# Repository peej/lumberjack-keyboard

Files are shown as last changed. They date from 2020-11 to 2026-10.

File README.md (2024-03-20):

# Lumberjack - Through-hole ortholinear 60% keyboard PCB

Lumberjack is a split 5x12 ortholinear keyboard PCB using through-hole components only.

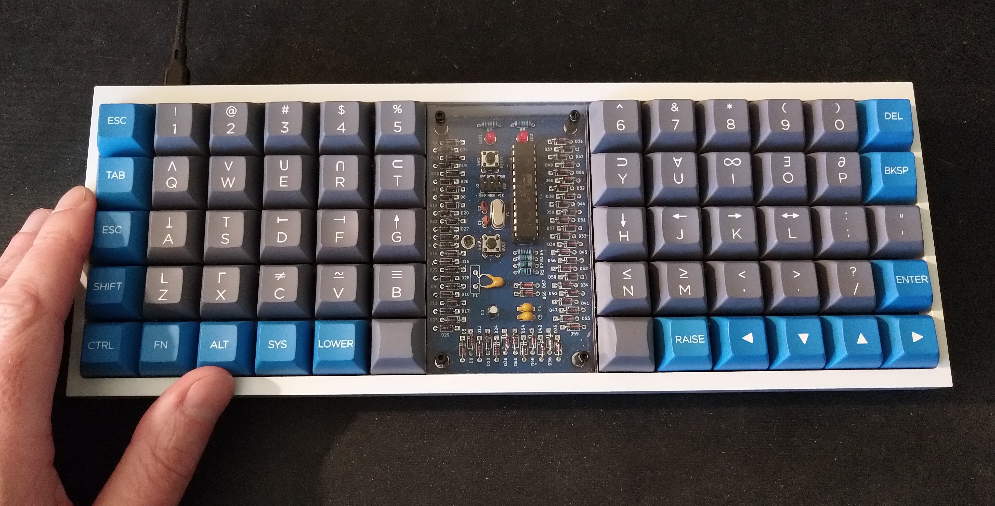
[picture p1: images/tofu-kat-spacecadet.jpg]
Tofu w/ KAT Space Cadet


The goal of this project is to build an all through-hole component ortholinear PCB that fits in a standard 60% tray mount case.

Inspired by the [Plaid keyboard](https://github.com/hsgw/plaid).

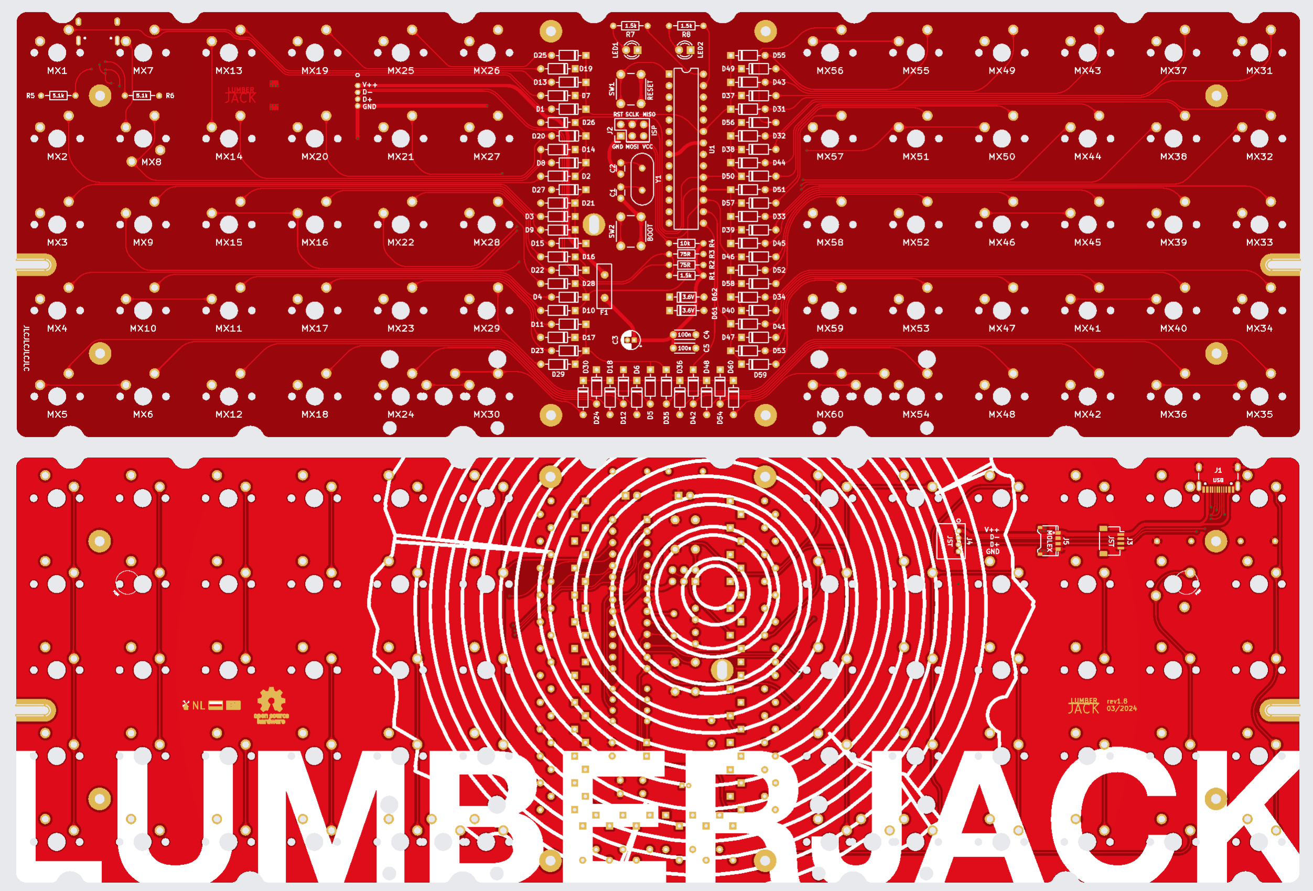
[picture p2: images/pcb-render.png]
PCB render


* Designed to be easy to build with minimal soldering experience.
* Get that visible component aesthetic in a standard 60% tray-mount case.
* 12 pin USB-C or JST connector.
* Plateless or with FR4 switch plates.

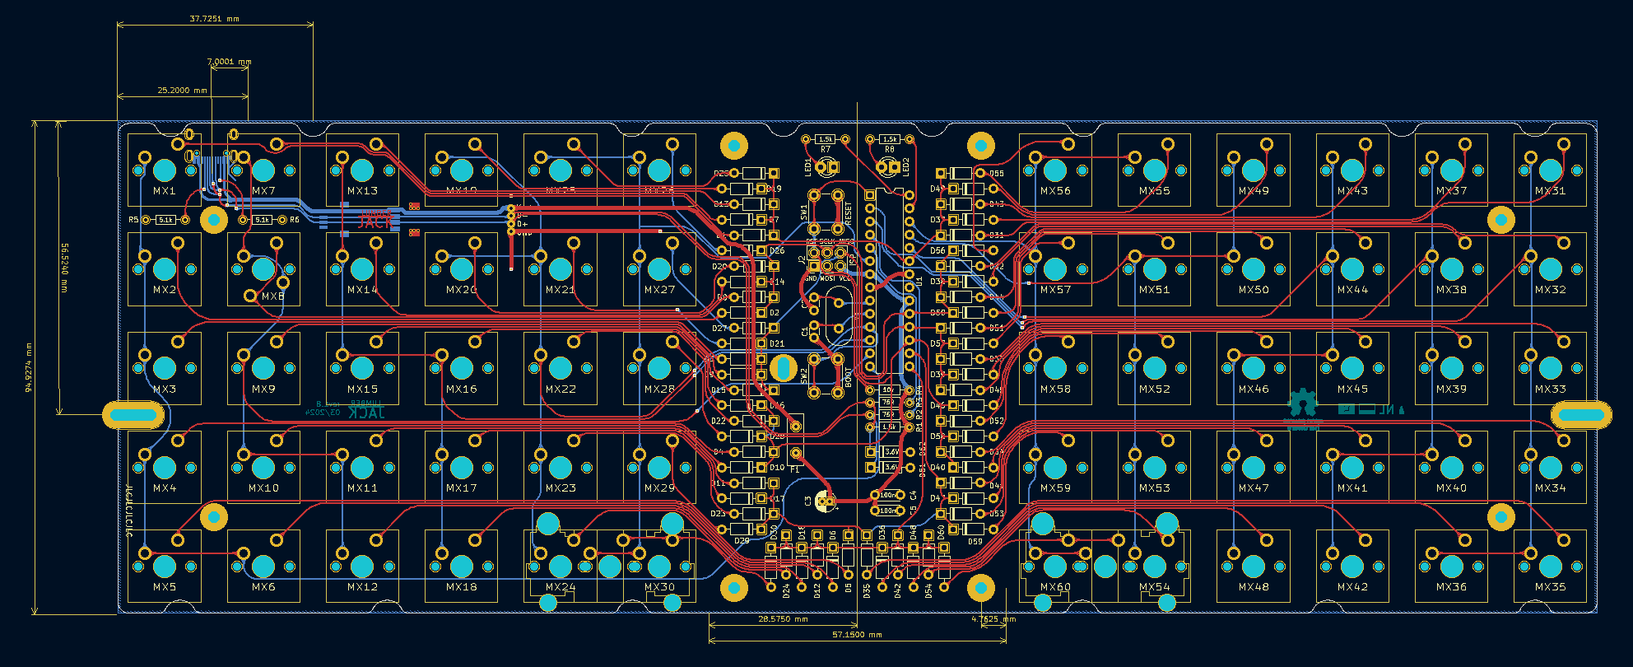
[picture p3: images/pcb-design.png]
PCB design


# Ordering parts

See the [Bill of materials](BOM.md) for a detailed list of the required parts.

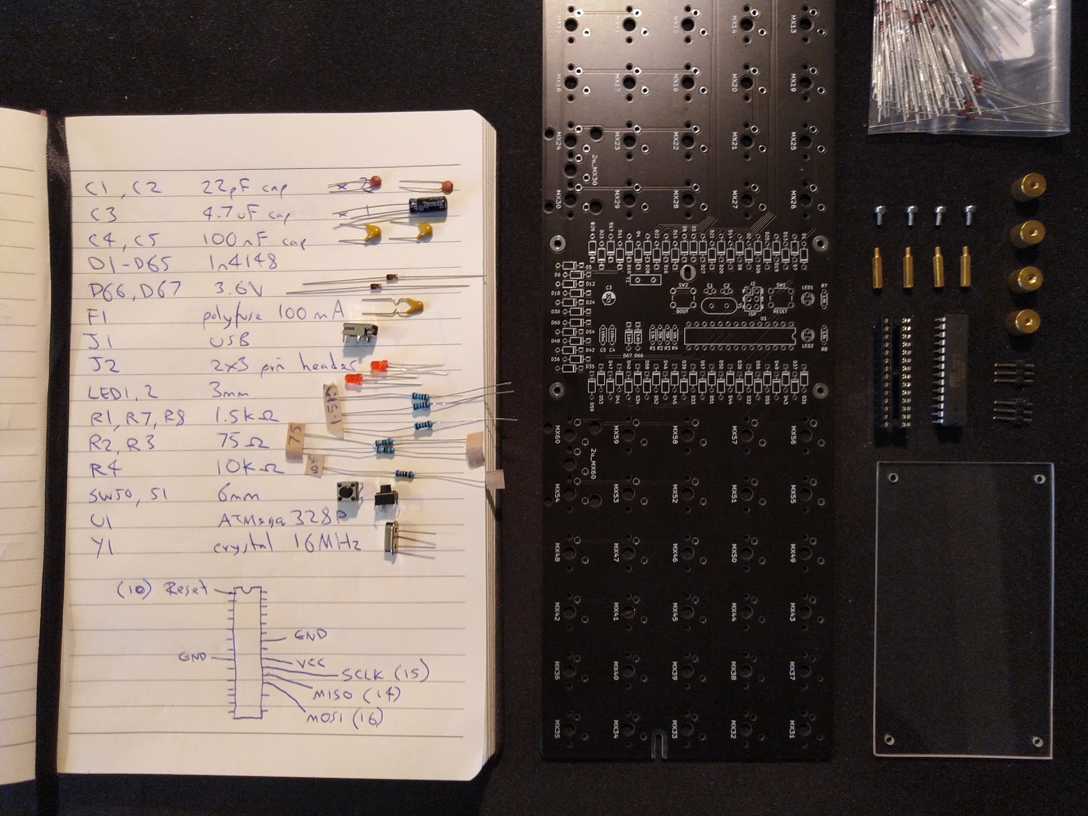
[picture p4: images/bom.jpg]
BOM


PCBs can be manufactuered by a variety of online PCB fabricators. You can use [PCBShopper](https://pcbshopper.com/) to search for the best price.

The [zip file in the gerber directory](https://github.com/peej/lumberjack-keyboard/blob/master/gerber/lumberjack.zip) contains the gerber files your fabricator will need to make the PCB.

When uploading the gerber zip files, use the default PCB settings.

Note that when uploading to JLCPCB, the upload tool may not detect the dimensions of the PCB from the gerber files and may not generate a preview image. This appears to be an issue with JLCPCB and you can manually enter the PCB size as 94.6x285mm.

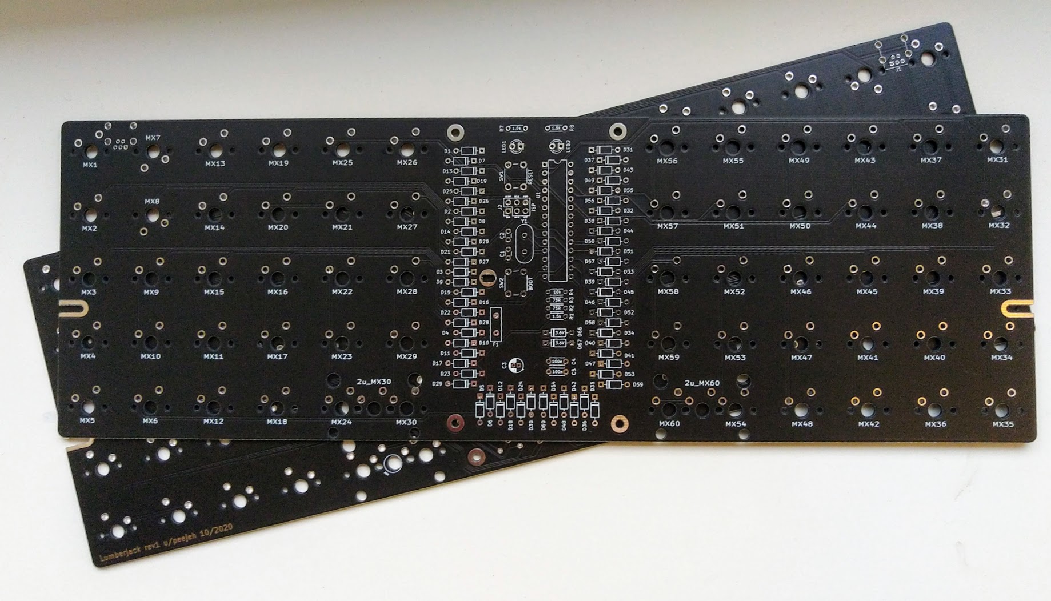
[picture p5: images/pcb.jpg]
PCB


If you want to use a plate, there are gerbers for an FR4 plate. You will need two plates, one for each half of the keyboard.

# Construction

Solder all the components onto the top side of the PCB except the USB connector which should be on the back of the board. Leave the larger components until last so that the board will lie flat upsidedown while you solder the resistors and capacitors.

Take care to put the correct value resistors and capacitors in the correct places, the values are written on the silkmask along with the component reference. If you are unsure about the value of a resistor, check it with a multimeter.

Ensure that polarised components (diodes, LEDs, electrolytic capacitor (C3), IC socket) are in the correct orientation. The square pad is for the negative side of the component; for a diode this means the side with the black stripe; for LEDs and C3 the short leg is the cathode and goes in the square pad.

See [the build guide](guide.md) for more information.

## Need help?

Have questions or need help, reach out via [our Discord server](https://discord.gg/cQ9EXqQmpE) where you will find many helpful Lumberjack owners.

# Firmware

Firmware is available in the QMK repository under the name `peej/lumberjack`.

Follow the [QMK firmware instructions](https://docs.qmk.fm/#/flashing) to build and flash the firmware.

To put the board into bootloader mode so it is ready to recieve firmware, press and hold the BOOT button (SW2) while pressing and releasing the RESET button (SW1). The board will now be detected as an USBasp device and can have the firmware flashed via the USB port.

Pressing the RESET button (SW1) on its own will restart the microprocessor. Once flashed with firmware it is neccessary to reset the keyboard so as to return control to the new firmware.

Note that due to the BOOT button (SW2) sharing a pin with column 3, when pressed the keys in that column will also activate. This is expected behavour but can be a little annoying or confusing if you are not expecting it.

## VIA

There is a VIA compatible firmware available in QMK. With this firmware flashed, the board will be automatically recognised by VIA when you plug it in.

## Bootloader

If you have a "raw" chip without a bootloader, you will need to compile and flash the bootloader onto the chip via another device. [See the build guide for more information](guide.md#bootloader).

## Matrix information

If you are building your own firmware, the following matrix information will be useful to you:

| Configuration | Value |
|---|---|
| MATRIX_ROWS | 6 |
| MATRIX_COLS | 10 |
| MATRIX_ROW_PINS | C0, B5, B4, B3, B2, B1 |
| MATRIX_COL_PINS | B0, D7, D6, D5, D4, D1, D0, C1, C2, C3 |
| DIODE_DIRECTION | COL2ROW |

Due to the limited pin number of the ATMEGA328P, the PCB uses a 6 by 10 matrix (16 pins) instead of a 5 by 12 matrix (17 pins), this makes organising the matrix in your firmware slightly more complicated. The image below shows pins for each key.

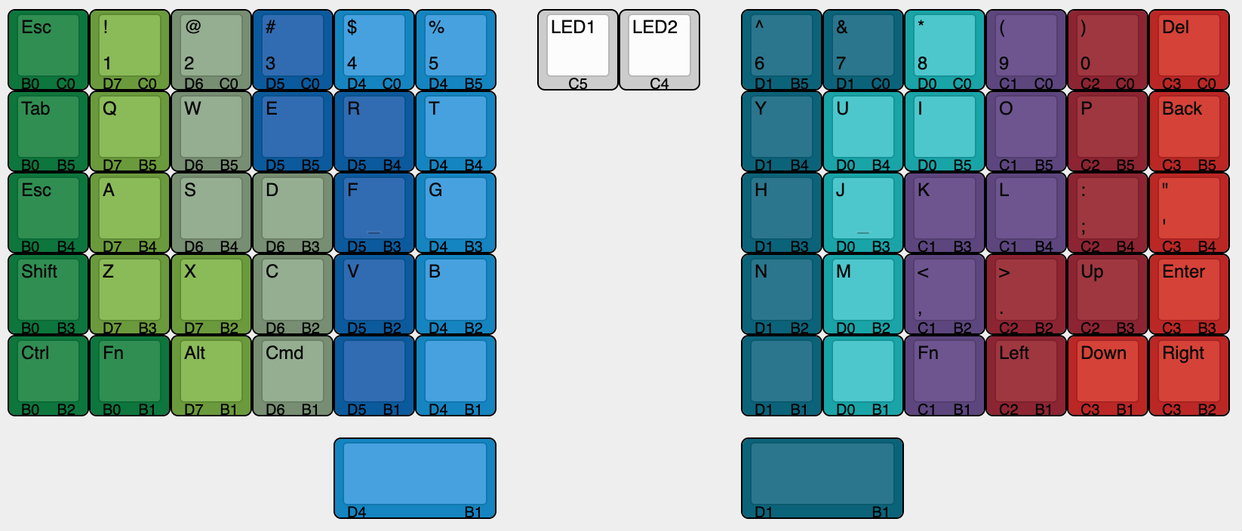
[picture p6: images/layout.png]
Layout pins

# Component cover

Cut a piece of 2mm thick acrylic to size (95x57mm) and drill 4 m2 holes in the corners for the standoffs. Use the PCB or cover.dxf as a guide for the hole positions, you can also use cover.dxf for laser cutting the correct size acrylic.

Affix the 4 standoffs to the PCB with screws from underneath the PCB. Use the remaining 4 screws to attach the acrylic to the top of the standoffs.

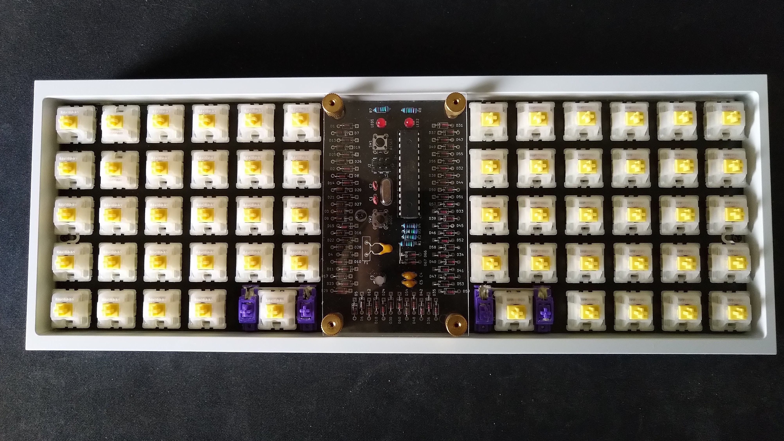
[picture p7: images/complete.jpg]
Completed build w/o caps


# Electronic component cradles

Want to give your components the comfort they need, right?

These 3d printable cradles for your electornic components provided by 
SuPaSeM#3659 (discord) will hold things in place, keep them neat and tidy, and cradle your components like a baby.

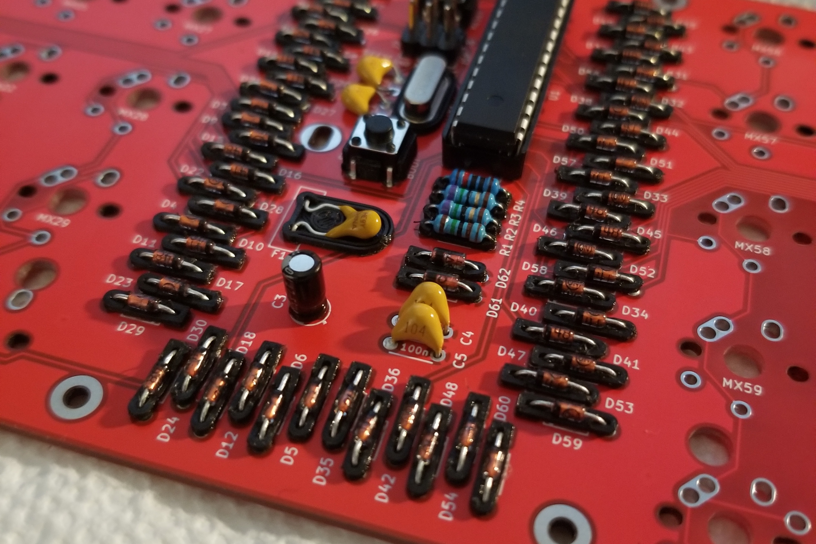
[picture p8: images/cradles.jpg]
Cradles preview


# Revisions

## Rev 1.1

* Fix cosmetic errors in silkscreen
* Increase resistor footprint size
* Fix R1 resistor connection to D-

## Rev 1.2

* Add JST socket footprint for USB daughterboard
* Rotate central mount hole 90 degrees

## Rev 1.3

* Add hybrid USB port footprint for mini and type C
* Fix numbering of zener diode footprints
* Flip MX7 to be south facing

## Rev 1.4

* Use USB footprint with better positioning
* Move 5.1k resistors to better location
* Change MX8 to allow both north and south facing switch
## Rev 1.5

* Change board outline to include cutouts for Bakeneko 60
* Re-route traces away from edges of the board
* Change MX footprints to MX/Alps/Choc combined footprint
* Add through-hole JST connector footprint
* Add silkscreen art to underside

## Rev 1.6

* Add mounting holes for standoffs so PCB can be used without a case

## Rev 1.7

* Change board outline to include cutouts for Cannon Keys Bakeneko and Singa Unikorn

## Rev 1.8

* Re-routed power and USB lines
* Change USB connector from THT to TYPE-C-31-M-12 SMD component
* Added fillets and curved traces
* Remove copper fill from top layer

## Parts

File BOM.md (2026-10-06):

# Bill of Materials (BOM)

BOM

| | Ref | Qty | Value or Part# | Description | Vendor Store |
|---|---|-----|---|---|---|
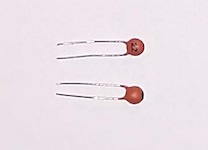
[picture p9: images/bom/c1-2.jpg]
C1,C2
|  | C1,C2 | 2 | 22pF p2.5mm | multilayer ceramic capacitor | |
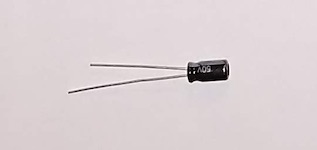
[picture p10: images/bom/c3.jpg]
C3
|  | C3 | 1 | 4.7uF p1.5mm | electrolytic capacitor | [秋月電子 [JP]](https://akizukidenshi.com/catalog/g/g117895/) |
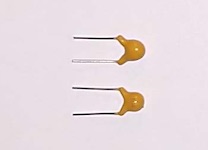
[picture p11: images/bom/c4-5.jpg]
C4,C5
|  | C4,C5 | 2 | 100nF p5.0mm | multilayer ceramic capacitor | |
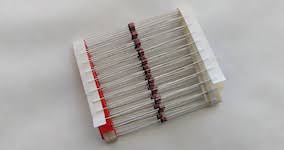
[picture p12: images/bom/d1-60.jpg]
D1-60
|  | D1-60 | 60  | 1n4148 | diode | [秋月電子 [JP]](https://akizukidenshi.com/catalog/g/g100941/) |
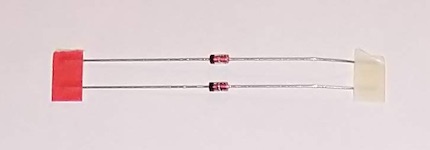
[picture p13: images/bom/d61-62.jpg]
D61,D62
|  | D61,D62 | 2 | 3.6V | zener diode | [秋月電子 [JP]](https://akizukidenshi.com/catalog/g/g115719/) |
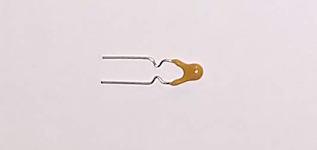
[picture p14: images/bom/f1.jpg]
F1
|  | F1 | 1 | 100mA | polyfuse | [秋月電子 [JP]](https://akizukidenshi.com/catalog/g/g112911/) |
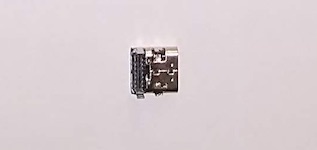
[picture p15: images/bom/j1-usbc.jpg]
USB
|  | J1 | 1 | TYPE-C-31-M-12 | USB-C connector | [Amazon [JP]](https://www.amazon.co.jp/dp/B09PKH9XZY) |
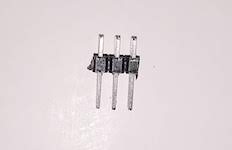
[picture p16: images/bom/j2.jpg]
J2
|  | J2 | 1 | 2x3 p2.54mm | AVR ISP pin header (optional) | |
| J3 | J3 | 1 | SM04B-SRSS-TB  | JST connector (optional for daughterboard) | |
| | J5 | 1 | 781710004 | Molex Pico-EZmate connector (optional) | |
| LED1,LED2  | LED1,LED2 | 2 | 3mm | LED | [秋月電子 [JP]](https://akizukidenshi.com/catalog/g/g111637/) (黄緑) / [秋月電子 [JP]](https://akizukidenshi.com/catalog/g/g111577/) (赤) |
| MX1-60 | MX1-60 | 60  | MX/Alps/Choc | Keyboard switch | |
| | Mill-Max  | 120 | 3305-1 | Mill-Max socket (optional for hot-swap) | [MOUSER [US]](https://www.mouser.jp/ProductDetail/575-3305115804720000) |
| R1,R7,R8 | R1,R7,R8  | 3 | 1.5kΩ | resistor | [秋月電子 [JP]](https://akizukidenshi.com/catalog/g/g116632/) |
| R2,R3 | R2,R3 | 2 | 75Ω | resistor | [秋月電子 [JP]](https://akizukidenshi.com/catalog/g/g116620/) |
| R4 | R4 | 1 | 10kΩ | resistor | [秋月電子 [JP]](https://akizukidenshi.com/catalog/g/g108550/) |
| R5,R6 | R5,R6 | 2 | 5.1kΩ | resistor for USB-C only | [秋月電子 [JP]](https://akizukidenshi.com/catalog/g/g108547/) |
| SW1,SW2 | SW1,SW2 | 2 | 6x6mm | tactile switch | [MOUSER [US]](https://www.mouser.jp/ProductDetail/611-645SL70SMTR92LFS) |
| U1 | IC socket | 1 | 28pin narrow | IC socket | [秋月電子 [JP]](https://akizukidenshi.com/catalog/g/g100013/) |
| U1 | U1 | 1 | ATMEGA328P-PU  | microcontroller | [MOUSER [US]](https://www.mouser.jp/ProductDetail/556-ATMEGA328P-PU) / [秋月電子 [JP]](https://akizukidenshi.com/catalog/g/g103142/) |
| Y1 | Y1 | 1 | HC49-4H 16MHz  | crystal | [MOUSER [US]](https://www.mouser.jp/ProductDetail/449-LFXTAL022786BULK) |
| cover | cover | 1 | 95x57x2mm | acrylic component cover | |
| screw | screw | 8 | M2 4mm | screws for standoff | |
| standoff | standoff  | 4 | M2 10mm | standoffs for component cover | |

For your convienience, here is the [BOM on Octopart](https://octopart.com/bom-tool/0k8Ap0AF).

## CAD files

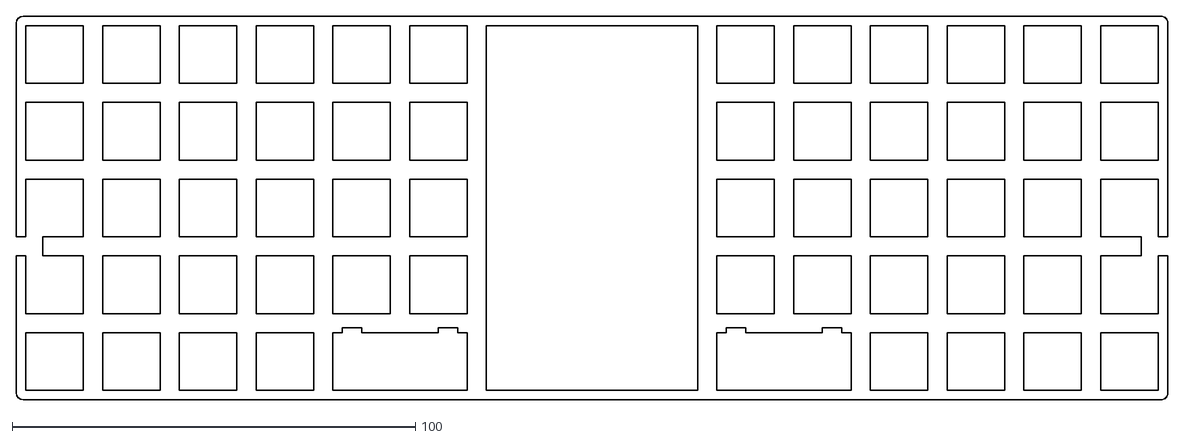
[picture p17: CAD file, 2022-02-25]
plates/lumberjack-full.dxf
285.8 x 95.3

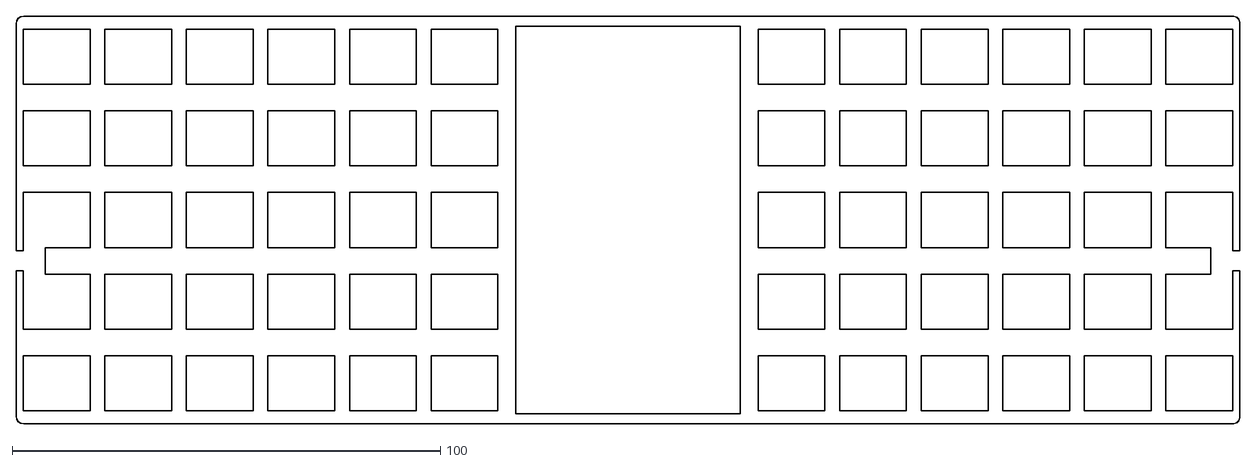
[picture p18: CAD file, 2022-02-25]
plates/lumberjack-alps-full.dxf
285.8 x 95.3

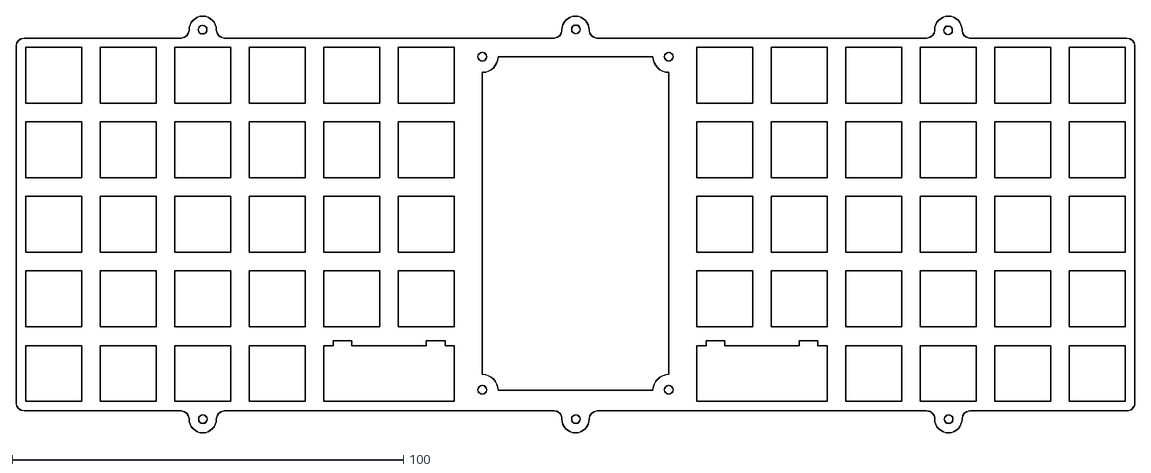
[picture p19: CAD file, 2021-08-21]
plates/brutal60-full.dxf
285.8 x 106.4

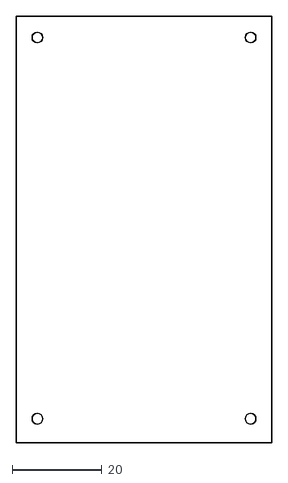
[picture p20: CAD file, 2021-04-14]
cover.dxf
57.2 x 95.2

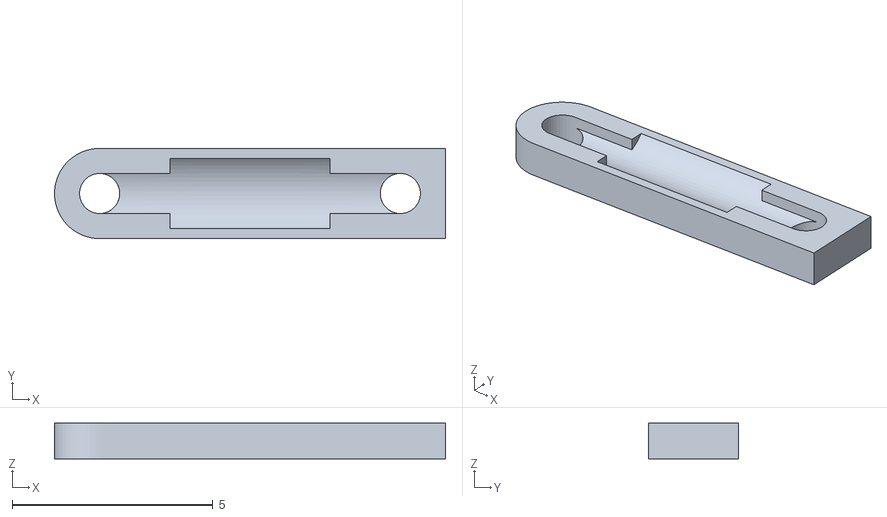
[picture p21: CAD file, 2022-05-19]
cradles/PolarizedDiodeCradle_x62.stl
9.75 x 2.25 x 0.889

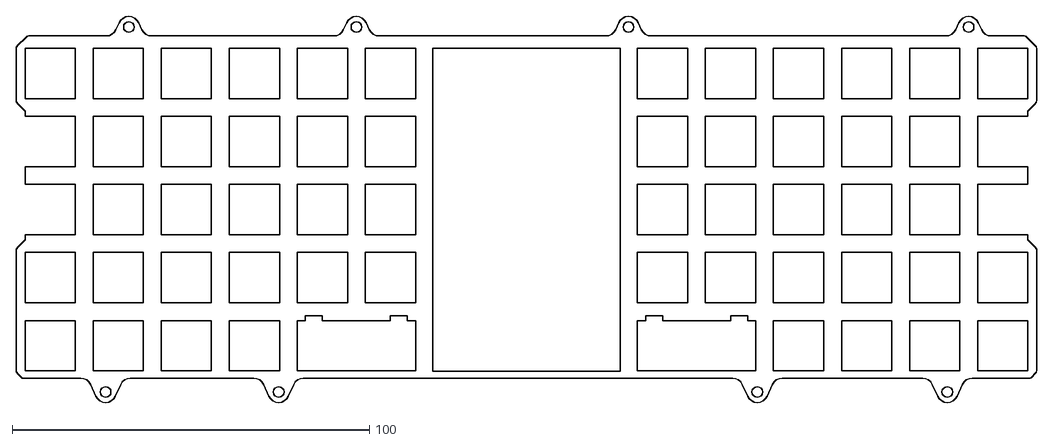
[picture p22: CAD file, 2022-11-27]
plates/lumberjack-frogmini.dxf
285.7 x 108.2

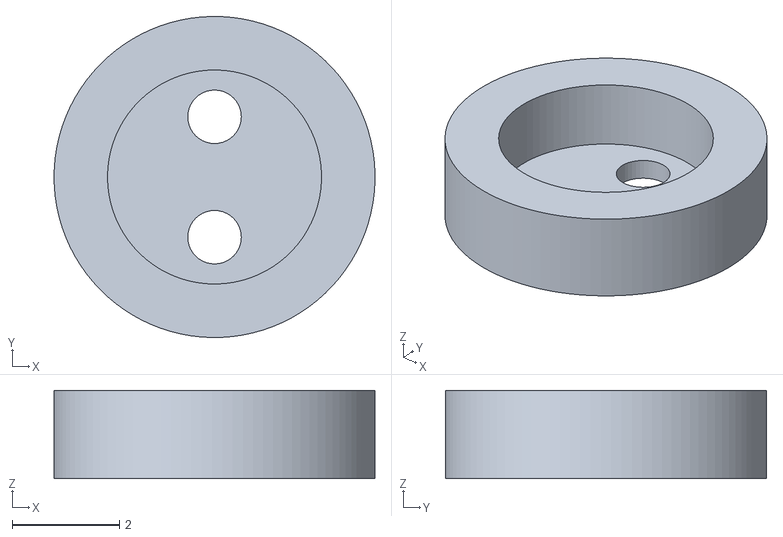
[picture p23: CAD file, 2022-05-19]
cradles/LEDcradle_x2.stl
6.00 x 6.00 x 1.65

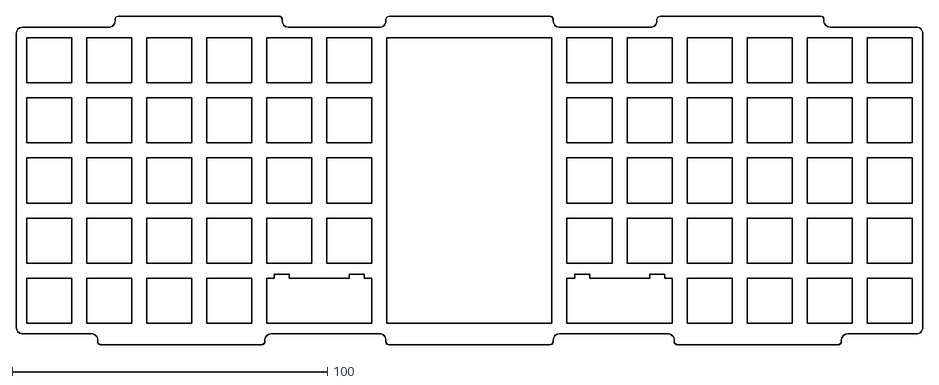
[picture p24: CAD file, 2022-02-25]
plates/lumberjack-polaris.dxf
287.7 x 104.2

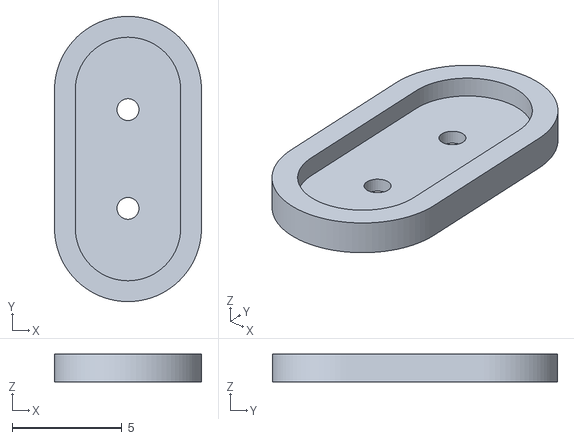
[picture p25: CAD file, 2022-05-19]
cradles/CrystalCradle_x1.stl
6.70 x 13.0 x 1.27

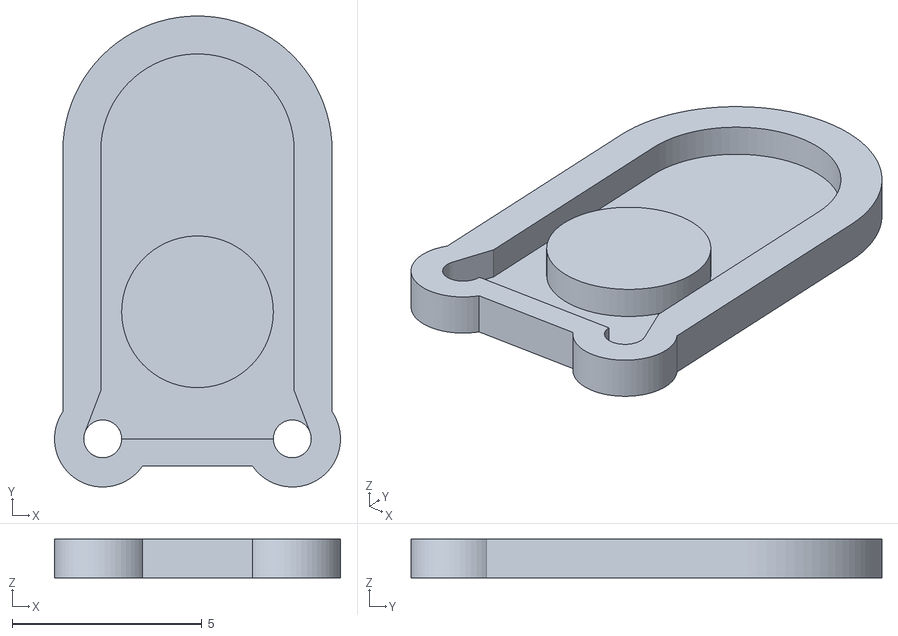
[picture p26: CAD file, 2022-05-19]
cradles/ResettableFuseCradle_x1.stl
7.54 x 12.4 x 1.02

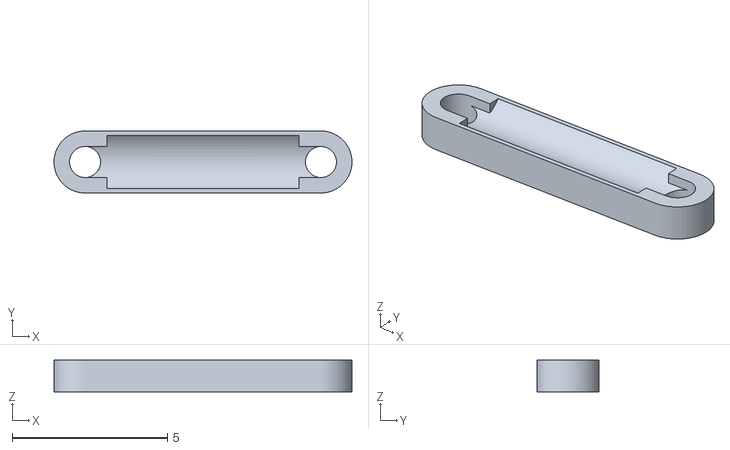
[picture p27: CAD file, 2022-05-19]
cradles/BlueResistorCradles_x6.stl
9.60 x 2.00 x 1.02

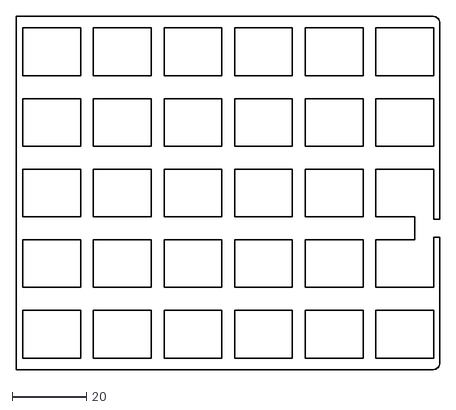
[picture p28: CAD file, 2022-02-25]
plates/lumberjack-alps.dxf
114.3 x 95.2

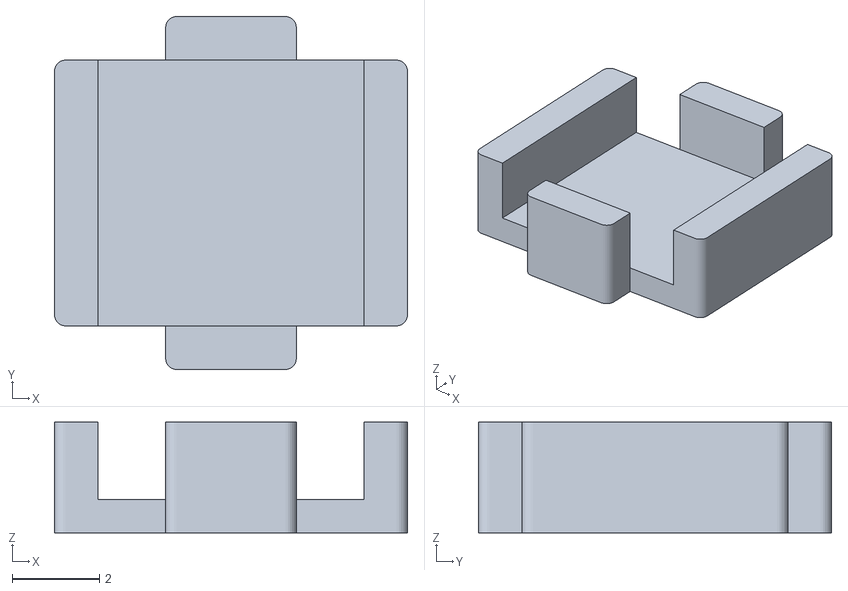
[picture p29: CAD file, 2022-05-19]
cradles/TactileSwitchCradle_x2.stl
8.10 x 8.10 x 2.54

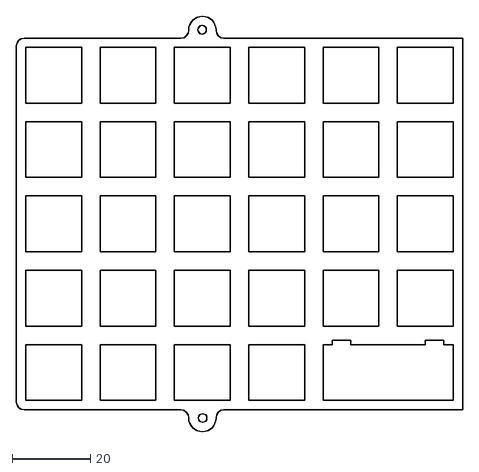
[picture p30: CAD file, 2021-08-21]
plates/brutal60-split.dxf
114.3 x 106.4

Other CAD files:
plates/lumberjack-split.dxf

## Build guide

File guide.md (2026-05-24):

# Lumberjack - Kit assembly guide

This assembly guide will guide you through putting together your Lumberjack keyboard PCB kit. The process is quite simple with only basic soldering experience.

## Before starting

* Check you have all the required items not included in the kit.
    * Soldering iron
    * Solder
    * Flush cutters
    * 60 MX key switches
* Check that you have all the components. See [BOM](BOM.md)
    * Keep the resistors in the paper reel so that it is easy to tell them apart based upon how many there are.
    * Do not confuse the 2 zener diodes with the 60 1N4148 diodes, they look almost identical but perform quite different functions.
* If you are not used to soldering, learn how to solder components.
    * https://learn.adafruit.com/adafruit-guide-excellent-soldering/tools

## Soldering

### USB connector (J1)
First you will solder the USB connector (or JST connector) to the **underside** of the PCB. All other components go on the top.

The connector is a surface mount device (SMD), meaning you will need to use a different soldering technique called drag soldering. You will need a separate supply of no-clean flux to do this, either liquid flux or a flux pen. Some isopropyl alcohol and a cotton bud is useful for cleaning up the flux residue afterwards.

* Tin the pads of the J1 footprint by adding a small amount of solder to each pad.
* Insert the USB connector into the board.
* Apply no-clean flux across all of the pads.
* Reheat the pads and press the USB port firmly into place to ensure it sits flat.
* The flux will cause the solder to flow to the pins and avoid creating solder bridges between the pins.
* Add more flux as needed as you go along.
* Use your iron between the pads to remove any solder bridges.
* Flip the board over and solder the legs into place.
* Check the solder joints carefully, under a magnifying glass if needed, to ensure there are no bridges between pads.

If you have a multimeter you can use it to check for bridges, put it into continuity mode and check that the following pins connect to each other and all others do not:

* Pins 1 & 12 are ground pins and should connect to each other and the ground pad of J4.
* Pins 2 & 11 are V+ pins and should connect to each other and the V+ pad of the J4.
* Pins 5 & 7 are D+ pins and should connect to each other and the D+ pad of the J4.
* Pins 6 & 8 are D- pins and should connect to each other and the D- pad of the J4.
* Pin 3 is the CC1 pin and should connect to the right pad of the R6 resistor only.
* Pin 9 is the CC2 pin and should connect to the left pad of the R5 resistor only.

#### JST connector (J3,4)

If you want to use a daughterboard instead of a USB connector, there are footprints for both a SMD or a THT connector. The connectors are positioned between the top and second row of switches so as to fall within the cable gutter of cases such as the Bakeneko, be aware that this might not be a suitable position for all cases.

Note: A JST connector is not included in the Lumberjack kit, the SMD variant is part JST-SR-4 and for THT it is S4B-ZR.

### Zener diodes (D61,62)

Solder the Zener diodes D61 and D62 (D66 and D67 in older PCB revisions).

Diodes are a polarized component and therefore take care of direction, the black line on the diode is the cathode and goes in the square pad on PCB.

Do not get these confused with the 1N4148 diodes.

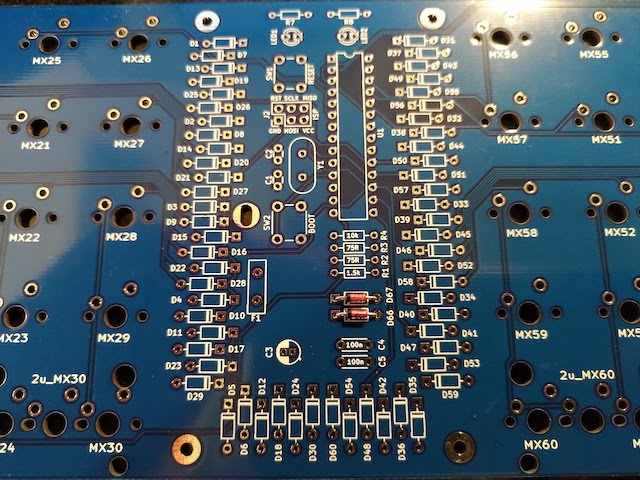
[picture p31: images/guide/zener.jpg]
Zener diodes


### Resistors (R1,2,3,4,7,8)

Solder the resistors.

Ensure you use the correct size resistor for the correct position. You can identify which resistors are which due to the number of resistors of each type in the kit or by matching the colored bands on the resistors.

* R1,7,8: 1.5kΩ Brown, green, black, brown, red
* R2,3: 75Ω Violet, green, black, gold, red
* R4: 10kΩ Brown, black, black, red, red

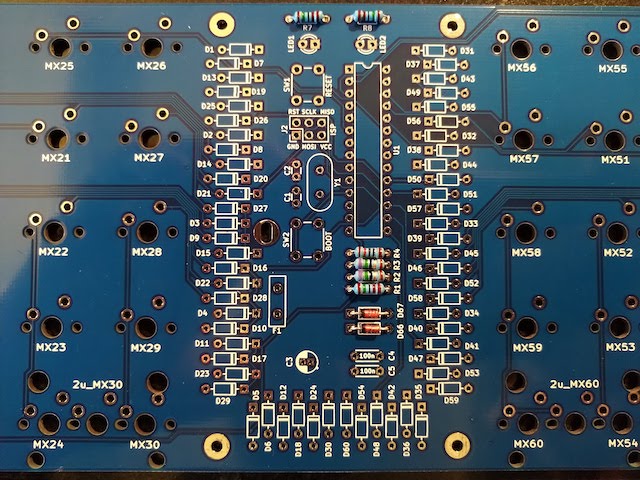
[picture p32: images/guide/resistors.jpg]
Resistors


### Resistors for USB-C (R5,6)

The USB-C connector requires two more resistors. They are marked in the kit with a black dot on the paper to help distingish them from the other resistors.

* R5,6: 5.1kΩ Green, brown, black, brown, red

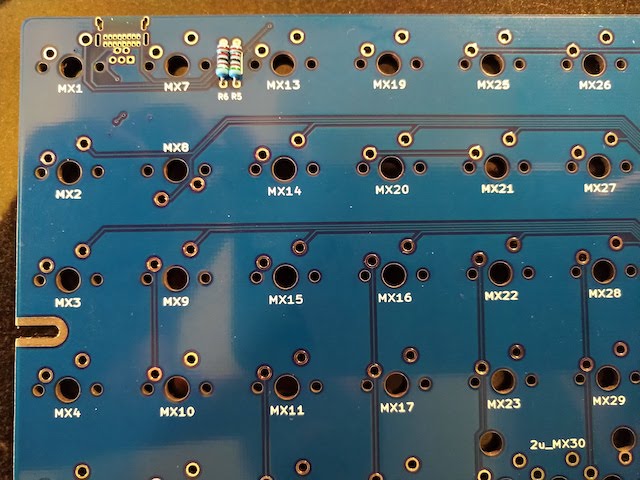
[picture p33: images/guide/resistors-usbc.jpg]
USB-C resistors


### Diodes 1N4148 (D1-60)

Solder the diodes.

Diodes are a polarized component and therefore take care of direction, the black line on the diode is the cathode and goes in the square pad on PCB.

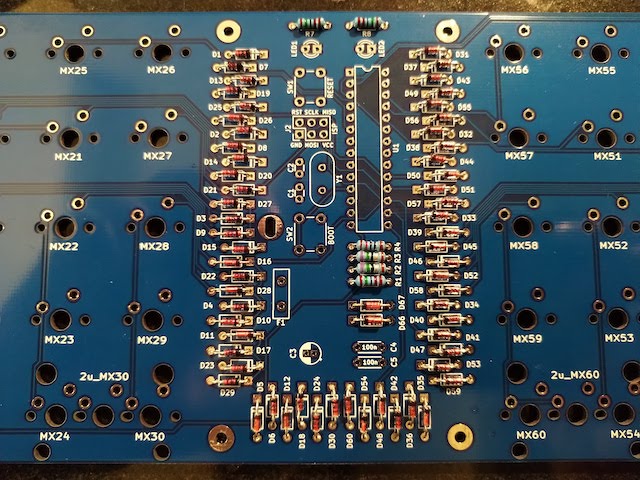
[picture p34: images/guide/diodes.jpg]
1N4148 diodes


### Crystal (Y1)

Solder the crystal.

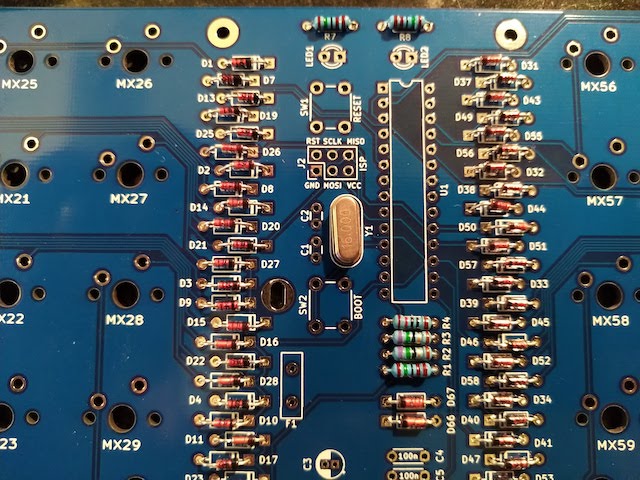
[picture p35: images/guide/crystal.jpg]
Crystal


### Capacitors (C1,2,4,5)

Solder the small brown (or yellow) 22pF capacitors C1 and C2 (marked 22).

Solder the small yellow 100nF capacitors C4 and C5 (marked 104).

Do not get the two sets of capacitors confused. Depending on the pitch of the capacitors, you might need to bend the legs so that they fit into the pads.

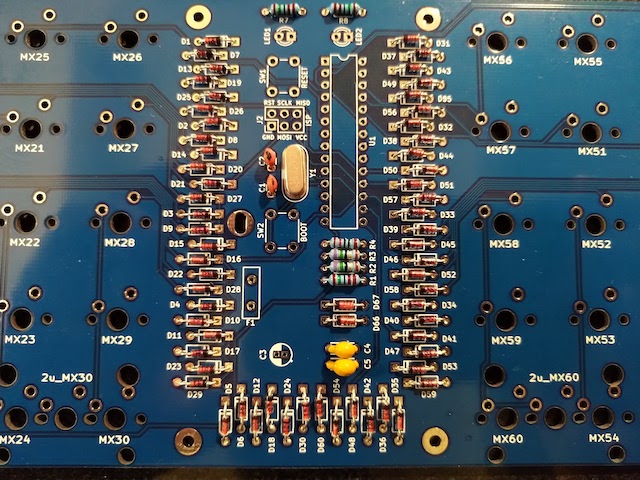
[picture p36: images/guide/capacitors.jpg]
Capacitors


Leave C3 until later as it is tall and will stop the PCB from laying flat making the other steps harder.

### LEDs (LED1,2)

Solder the LEDs.

LEDs are a polarized component and therefore take care of direction, the short leg is the cathode and goes in the square pad on PCB.

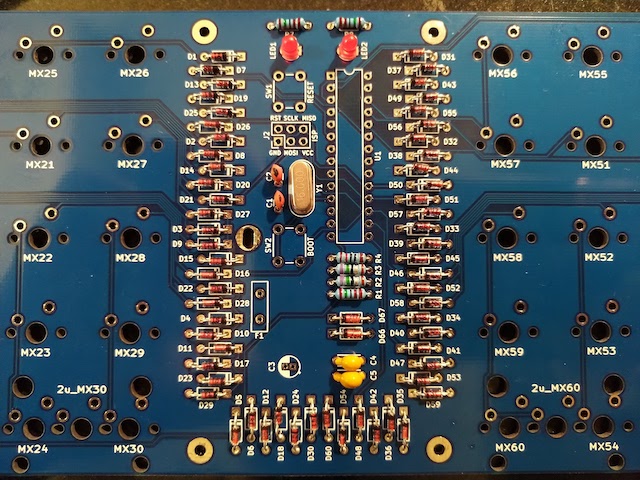
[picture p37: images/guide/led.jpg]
LEDs


### IC socket (U1)

Solder on the IC socket. 

The IC socket mounts a polarized component, check the notch on silkscreen and IC Socket.

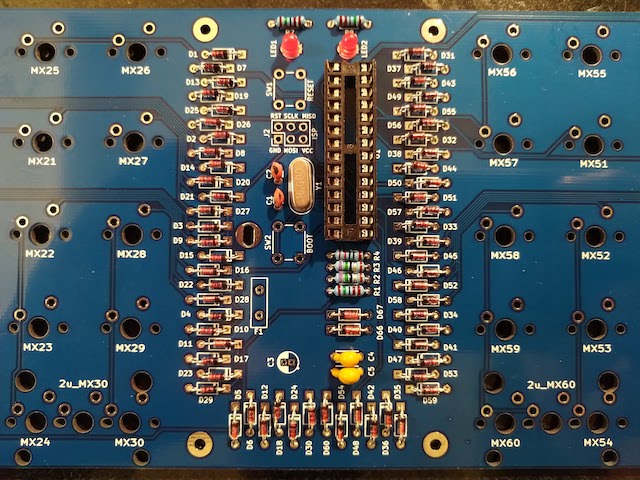
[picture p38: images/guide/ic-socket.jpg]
IC Socket


Do not insert microcontroller into the socket before soldering the socket to the PCB.

### Electrolytic capacitor (C3)

Electrolytic capacitor is a polarized component, the short leg is the cathode and goes in the circular (left) pad on PCB (nearest the C3 marking).

The soldermask around the pads can cause confusion as to which pad is which. The circular pad has a white square pattern around it making it look like it is square, so be careful and double check. The capacitor should be orientated so that the side with the line on it is on the left.

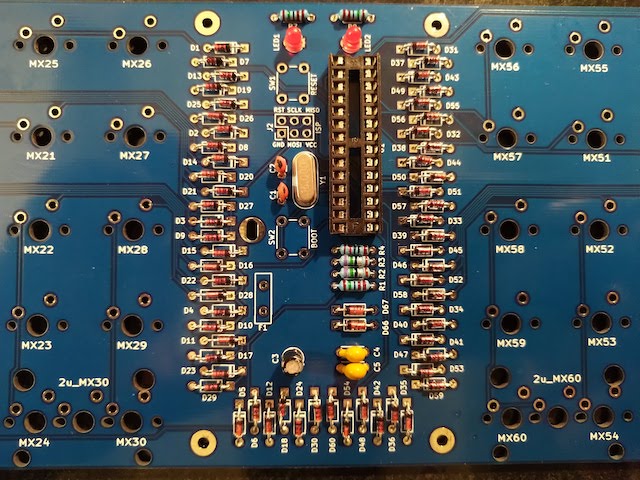
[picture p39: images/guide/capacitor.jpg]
Capacitor


To fit under the component cover, ensure that your capacitor body is less than 10mm tall.

If your capacitor is taller than 10mm and will not fit under the component cover, you can alternatively bend the legs and lie the capacitor down into the empty space on the PCB above the pad.

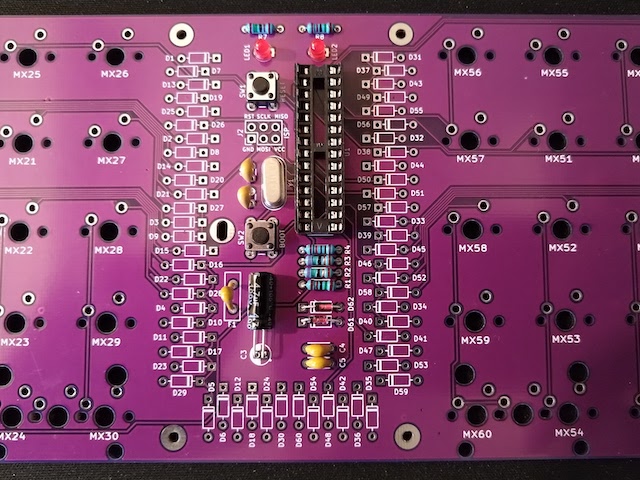
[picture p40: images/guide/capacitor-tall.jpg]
Tall capacitor


### Resettable fuse (F1)

Solder on the resettable fuse.

After soldering, bend the fuse over to that it lays flat on the PCB.

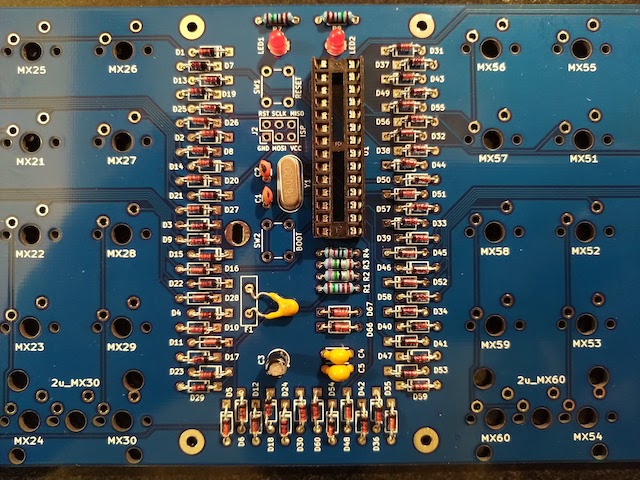
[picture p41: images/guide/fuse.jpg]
Fuse


If you have placed the capacitor into the empty space that the fuse would usually occupy, straighten the legs of the fuse with pliers before soldering it so that it can be soldered lower into the PCB.

### Tactile switches (SW1,2)

Push the switches into the PCB and solder the legs.

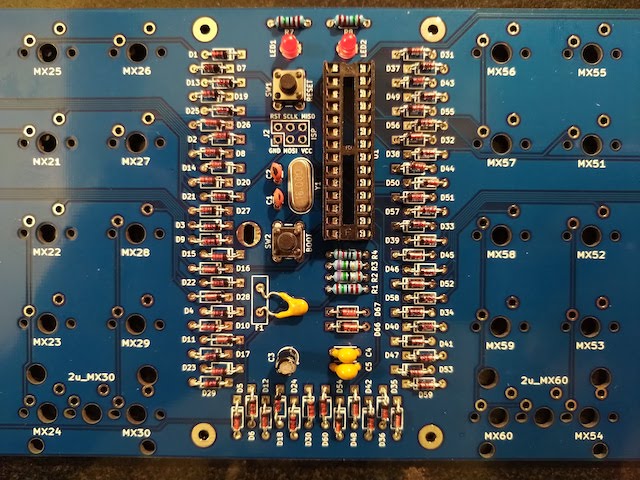
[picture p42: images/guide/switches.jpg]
Push switches


### ISP header (J2)

Used for programming the microprocessor with the bootloader directly. If your MCU is already programmed you can skip adding this header if you want.

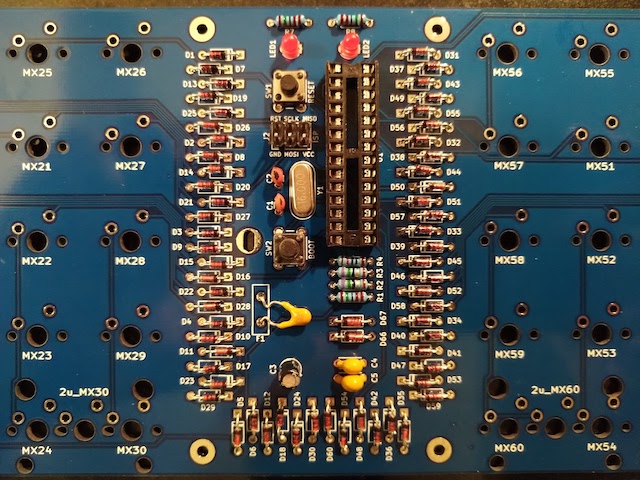
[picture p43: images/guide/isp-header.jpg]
ISP header


### ATMEGA328P (U1)

Insert ATMEGA328P into IC Socket.

You will probably need to carefully bend the legs to make it fit into the socket. Take care and gently bend them against a flat surface until they are spaced correctly for the socket.

Ensure that you insert it in the correct orientation, the semicircular mark should match that of the silkscreen.

Take care that all the legs go into the socket correctly and do not get accidently bend outside of the socket. The end legs are small and fragile, repeated bending of the legs can cause them to break off.

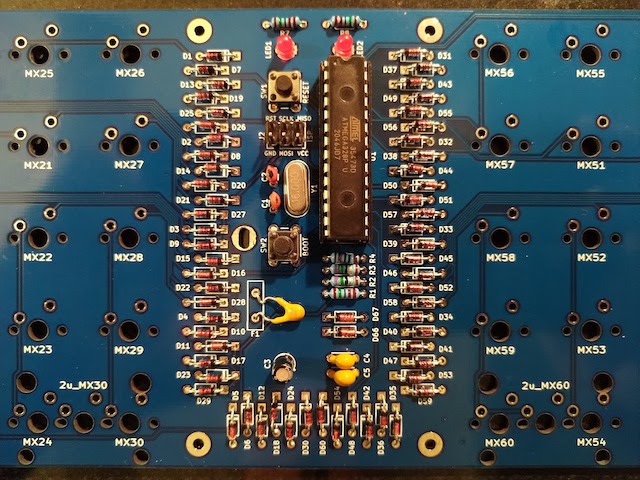
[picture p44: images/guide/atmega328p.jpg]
ATMEGA328P


### Check list

Before connecting the board to your computer, a few things to double check just to be safe:

* Take a close look at the USB connector pins and visually check there is no short between the VCC and GND pins. If you have a multimeter, now might be a good time to use it.
* Check the orientation of polarized components (ATMEGA328p, diode, electrolytic capacitor).
* Double check the correct resistor values are in the correct locations.

## Software

Note: If you got your Lumberjack as a kit, the microprocesor is already flashed with a bootloader and firmware, and you can skip this and the firmware steps.

### Bootloader

A bootloader is a piece of software on the microprocessor which can be used to flash firmware onto the microprocessor and to pass execution control to that firmware.

You will need to flash the microprocessor with a bootloader. To do this you will need another device which can be connected to the ISP headers and used to flash the bootloader to the chip. Since Lumberjack is the same as the Plaid, we can use the same bootloader.

* Download the [Plaid bootloader](https://github.com/hsgw/USBaspLoader/tree/plaid) and follow the instructions to compile the bootloader.
* Follow the [QMK ISP flashing guide](https://docs.qmk.fm/#/isp_flashing_guide) to get the bootloader onto the chip.

Don't forget to set the fuses: low `0xd7`, high `0xd0`, extended `0xfc`.

There is a pre-compiled bootloader + firmware in the [bootloader directory](bootloader) along with an example `avrdude` command for flashing it.

### Firmware

Follow the [QMK firmware instructions](https://docs.qmk.fm/#/flashing) to build and flash the firmware.

`qmk flash -kb peej/lumberjack`

To put the board into bootloader mode so it is ready to recieve firmware, press and hold the BOOT button (SW2) while pressing and releasing the RESET button (SW1). The board will now be detected as an USBasp device and can have the firmware flashed via the USB port.

Pressing the RESET button (SW1) on its own will restart the microprocessor. Once flashed with firmware it is neccessary to reset the keyboard so as to return control to the new firmware.

Note that due to the BOOT button (SW2) sharing a pin with column 3, when pressed the keys in that column will also activate. This is expected behavour but can be a little annoying or confusing if you are not expecting it.

### Can't recognize bootloader

* Check components and soldering near ATMEGA328p.
    * Direction of ATMEGA328p
    * BOOT SW and RESET SW
    * USB connector
    * R1, R2, R3, D66, D67
* Try different USB cable, PC, USB hub
    * If you connect via USB hub, try connecting directly.

### Check list

Now the board should be fully functional, so check that everything works before adding the switches.

Plug in the PCB and use a pair of tweazers or a piece of wire to check each keyswitch pad triggers a keypress.

## Switches

### Stabilizers

If you are using 2u keys and want to use key stabilizers, fix them to the board before inserting the switches.

If you are using screw in stabilizers, be aware that the screws can cause a short to the unused switch pads for the 1u keys. To avoid this, use plastic washers or electrical tape under the screws to isolate them from the PCB.

### Trim switch legs

When fitting key switches, the switches at the 'Q' and 'P' positions on the 2nd row will foul on the standoffs in your keyboard case, so you need to trim down one of the stabilizing pins and part of the center pin to ensure the PCB fits flush within the case.

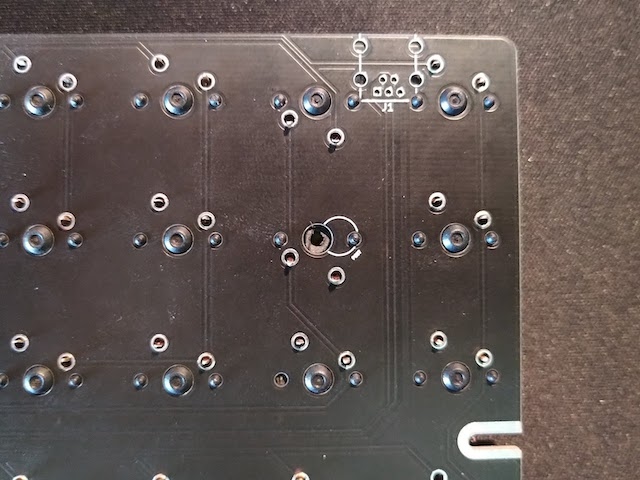
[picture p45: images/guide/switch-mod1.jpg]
Switch legs


If you are using a 2u key on the right hand side, you will also need to trim down the center pin so that it does not foul on the standoff. The position the case standoffs will be is marked on the soldermask of the underside of the PCB.

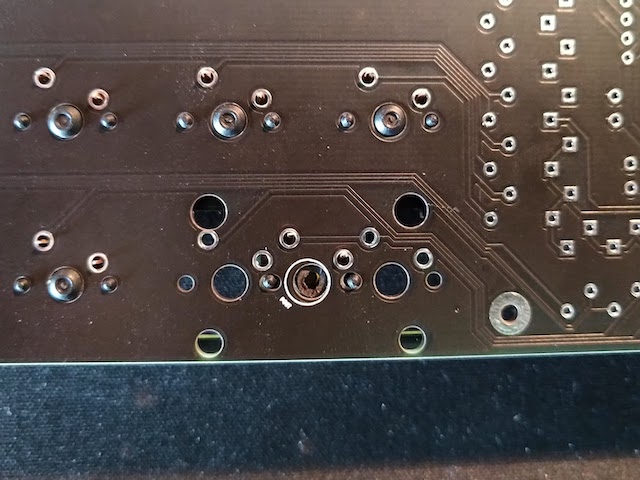
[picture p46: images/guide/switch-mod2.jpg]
Switch center pin


### Insert switches

Insert the switches into the PCB and solder the pins of each switch.

If you are using a plate, insert the switches into the plate first and then insert into the PCB.

Ensure that the switch is fully inserted and sitting flush with the PCB before soldering.

Note also that the switch at the 'Q' position is upsidedown so that the switch pins do not interfere with the case standoffs.

## Component cover

Affix the 4 standoffs to the PCB with screws from underneath the PCB. Use the remaining 4 screws to attach the acrylic to the top of the standoffs.

Do not overtighten the screws as this could crack the acrylic.

## Case fitting

When fixing the PCB to your case you will only use the center, the left and the right screw holes. Depending on your case design, the PCB will be supported by the other standoffs.

## End

Congratulations, your build is complete.

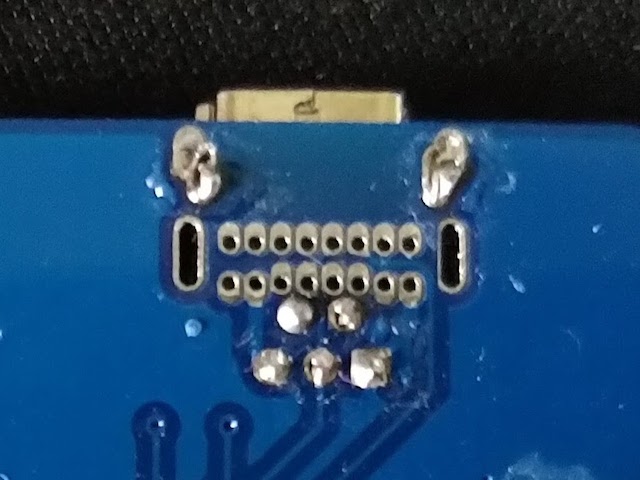
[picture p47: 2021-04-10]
images/guide/usb.jpg

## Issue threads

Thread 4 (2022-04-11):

10k ohm resistor part number

rjorgenson-ns, 2022-04-11:
Hi,

I am trying to build a lumberjack and going off the BOM the part number for the 10k ohm resistor of `CCF6010K0FKE36` appears to be a larger 8-10mm resistor that doesn't fit on the board design. Is there another part number for the smaller size resistor that will fit? This is the data sheet for the resistors I got from mouser based on the part number https://www.mouser.com/datasheet/2/427/VISH_S_A0001810520_1-2567648.pdf

peej, 2022-04-11:
Oh good spot, sorry about that. You need the regular 6mm resistors, so something like `CMF5510K000BEBF` https://www.mouser.com/ProductDetail/?qs=Ymhh3MYumTmqMFwWXOXsVg%3D%3D (or https://www.aliexpress.com/item/32952657927.html if you want bulk from China).

I've updated the BOM on Octopart for all the resistors.

rjorgenson-ns, 2022-04-12:
Awesome thanks, ordered some so I can get this build done =] can't wait!

Closed 2022-04-12.

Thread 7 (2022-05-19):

Current gerbers don't have default dimensions

Wanja-L, 2022-05-19:
When uploading the zipped PCB gerbers from latest master to JLCPCB the dimensions aren't automatically filled in:

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

If I switch to tag 1.6 and upload those gerbers it fills them in:

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

Not sure if the dimensions stayed the same between the versions so I figured I'd raise it here.

I'd open a PR but I have no idea how to use KiCad. I'll download it and see if I can figure it out but if you beat me to it I wouldn't be mad either :)

peej, 2022-05-19:
This appears to be an issue with the JLCPCB gerber loader, if the gerbers take too long to process for whatever reason then it cannot determine the size of the PCB.

I've tried exporting the gerbers with different settings but nothing I've tried appears to "fix" the issue.

Gerbers themselves only contain the shapes, JLCPCB determines the PCB size from the shapes in the outline layer within the gerber.

Perhaps an update to the documentation specifying this and the PCB dimensions to use would be the best solution until JLCPCB fix their form.

Wanja-L, 2022-05-19:
Thanks for the quick response. I was about to start a PR and saw that you beat me to it, much appreciated.

Closed 2022-05-19.

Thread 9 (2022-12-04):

LED 1/2 Purpose?

aggrofart, 2022-12-04:
Hi! When I was testing the switch contacts, all work and light up LED 1 except for 3: MX6, 24 & 54. When I test the contacts for these 3, **LED 2** lights up instead and the corresponding keys do not register on my computer.

Can I check what I did wrong? I checked the diodes and it appears to be soldered in the correct direction.
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

peej, 2022-12-04:
In the default firmware in the QMK repo, LED1 is set to light up upon keypress, while LED2 on layer change, and keys 6, 24 and 54 are all bound in the default keymap to layer change, thus you see LED2 light up for these keys.

Layer changes also doesn't sent a OS recognisable keycode to your computer, so you won't see a keypress. If you are testing using VIA, you should enable matrix test mode to test all the keys.

aggrofart, 2022-12-05:
Thanks, this really helped! I'll also use VIA to test the build out. 😁

Closed 2022-12-05.

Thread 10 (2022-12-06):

Lumberjack loses connection after a few seconds

aggrofart, 2022-12-06:
Hi, got another issue. When I plugged into my PC, VIA detects it for a few seconds but then stops detecting it. On Device Manager, the USB device was unknown and had a code 43 (Device descriptor request failed). I tried connecting it to another laptop and my friend's macbook but it could not be detected either.
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

You can check out a [short video that I recorded here for your reference](https://drive.google.com/file/d/1BxSn88kvvxoeLK0G6eAC08KTEaQVHmbv/view?usp=share_link).
After leaving the board alone for >1 hour, I can connect it again and the issue repeats. 😅

Hope you can help with this! (:

AldaCL, 2022-12-06:
If another computer didn't recognize the device it sounds like an ATMega issue or some charge remaining in the capacitors (which sounds very rare).

Did you already tried to reboot firmware/reload Bootloader?
Can you check if there is any short/bridge between adjacent pins?
Also you could check if there is some voltage drop on vcc/gnd, probably some of your components are generating some extra consume.
Finally, when the device disconect, can you try to short the pins of the C3 capacitor, and check inmediatly if the device is recognized.

I had similar issue, but with intermittent connection/disconnects, the reason were some dust in the usb port

aggrofart, 2022-12-08:
Thanks for the suggestions @AldaCL!

> Did you already tried to reboot firmware/reload Bootloader?
I tried pressing both reset and boot switches but the problem remains.

> Can you check if there is any short/bridge between adjacent pins?
None that I could see.
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

> Also you could check if there is some voltage drop on vcc/gnd, probably some of your components are generating some extra consume.
How do I do this? I have a multimeter but am only used to checking for continuity. 😅

> Finally, when the device disconect, can you try to short the pins of the C3 capacitor, and check inmediatly if the device is recognized.
Tried but still doesn't work. 😐

aggrofart, 2023-01-09:
Hi, just to update that I desoldered the USB C connector (together with the R5, R6 resistors) and soldered on a mini USB connector instead to solve this issue. Closing this. Thanks for the help regardless! 😁

Closed 2023-01-09.

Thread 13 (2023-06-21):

Windows, and QMK tookbox doesnt recognize my board.

M0B1, 2023-06-21:
Hi there, I just recently finished putting together a kit for a lumberjack that i ordered from KEEBD, ive checked all my soldering and placement of parts too many times to count now and despite any efforts ive made to try and fix my issue as a windows problem im still gettting Usb error 43 (device not recognized) please help.

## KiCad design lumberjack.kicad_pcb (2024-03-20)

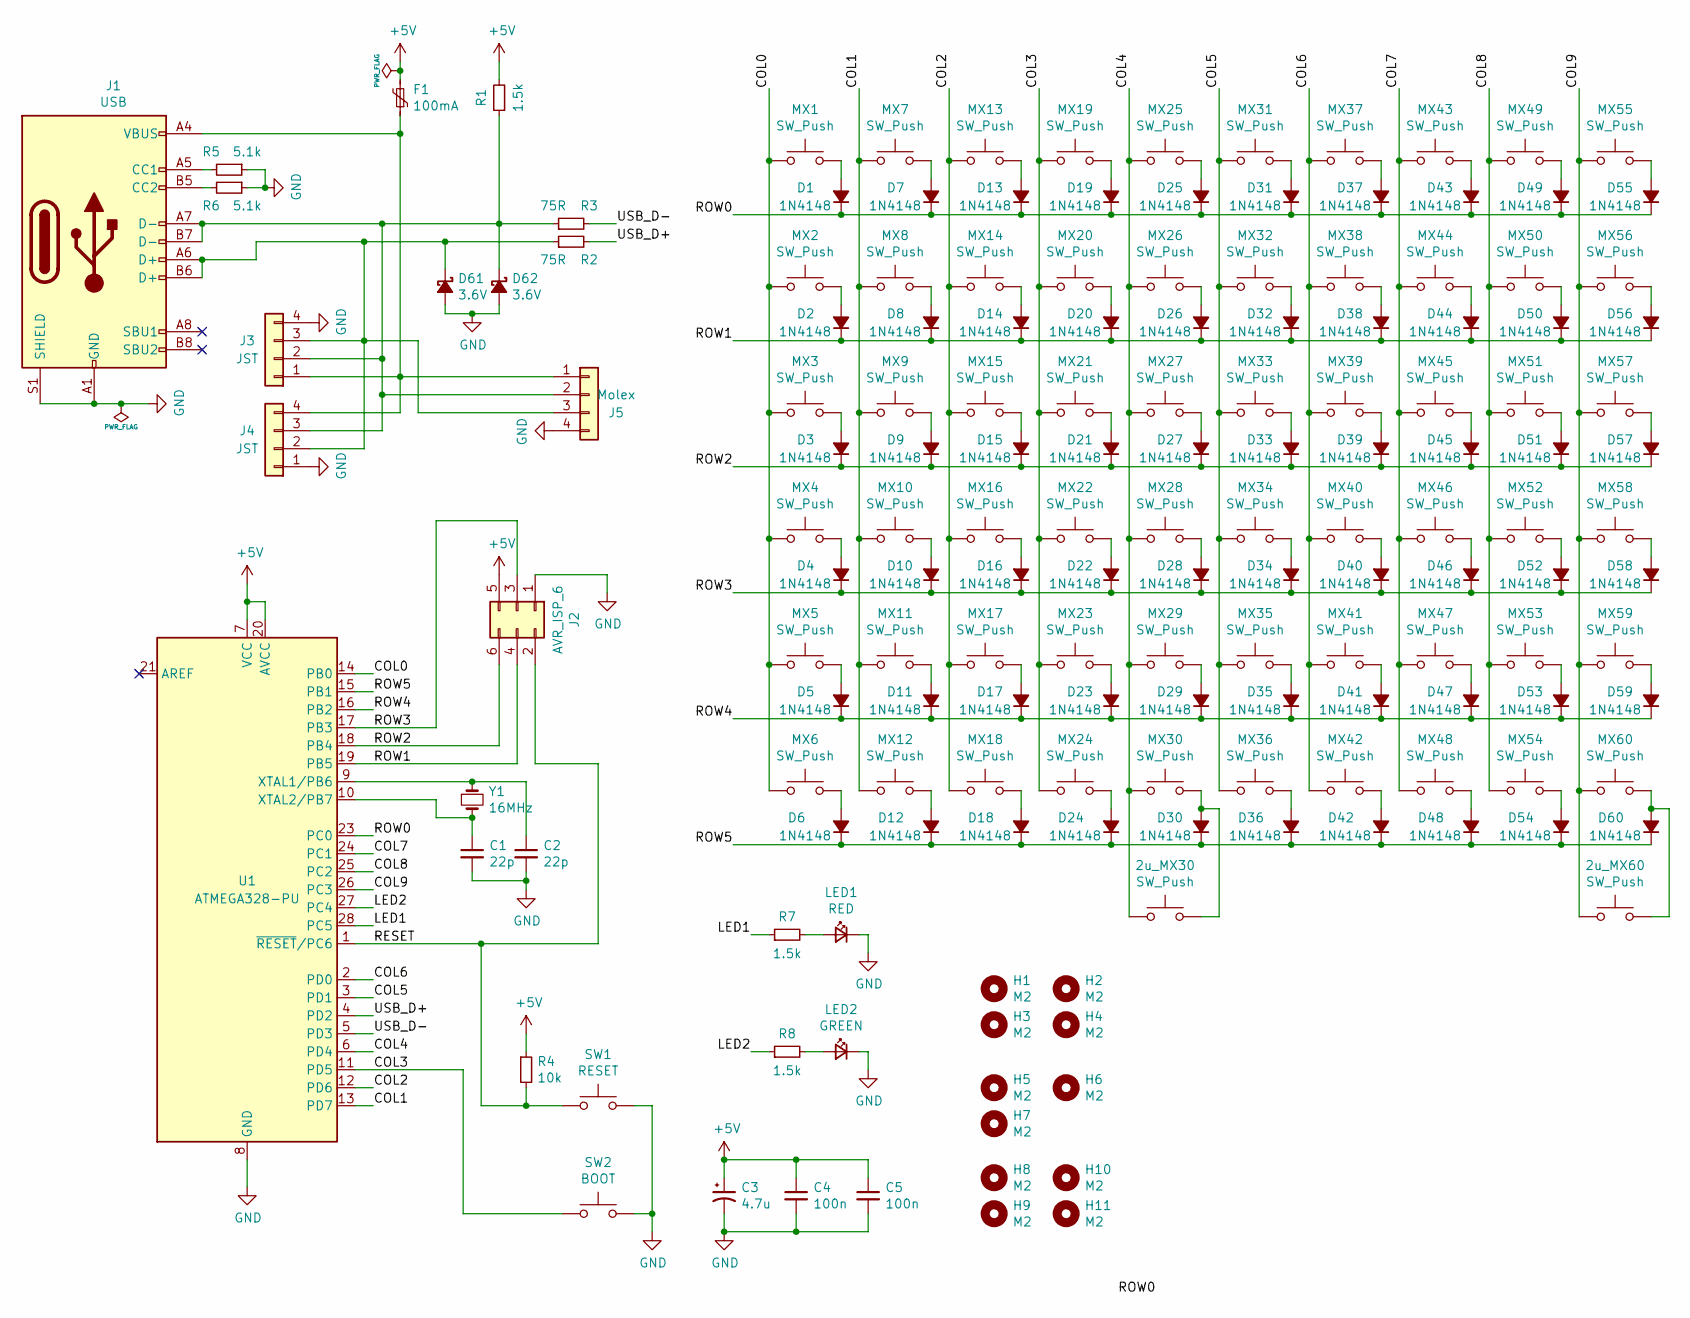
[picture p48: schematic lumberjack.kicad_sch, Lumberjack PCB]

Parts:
2u_MX30, 2u_MX60: SW_Push; MX_PCB_200B
C1, C2: 22p; C_Disc_D3.0mm_W1.6mm_P2.50mm
C3: 4.7u; CP_Radial_D4.0mm_P1.50mm
C4, C5: 100n; C_Disc_D4.3mm_W1.9mm_P5.00mm
D1, D2, D3, D4, D5, D6, D7, D8, D9, D10, D11, D12, D13, D14, D15, D16, D17, D18, D19, D20, D21, D22, D23, D24, D25, D26, D27, D28, D29, D30, D31, D32, D33, D34, D35, D36, D37, D38, D39, D40, D41, D42, D43, D44, D45, D46, D47, D48, D49, D50, D51, D52, D53, D54, D55, D56, D57, D58, D59, D60: 1N4148; D_DO-35_SOD27_P7.62mm_Horizontal
D61, D62: 3.6V; D_DO-35_SOD27_P7.62mm_Horizontal
F1: 100mA; Fuse_Bourns_MF-RHT100
H1, H2, H3, H4, H8, H9, H10, H11: M2; MountingHole_M2
H5, H6, H7: M2; MountingSlot_M2
J1: USB; TYPE-C-31-M-12
J2: AVR_ISP_6; PinHeader_2x03_P2.54mm_Vertical
J3: JST; JST_SH_SM04B-SRSS-TB_1x04-1MP_P1.00mm_Horizontal
J4: JST; S4B-ZRLFSN
J5: Molex; PicoEZMate-Reinforced-Lite
LED1: RED; LED_D3.0mm
LED2: GREEN; LED_D3.0mm
MX1, MX2, MX3, MX4, MX5, MX6, MX7, MX9, MX10, MX11, MX12, MX13, MX14, MX15, MX16, MX17, MX18, MX19, MX20, MX21, MX22, MX23, MX24, MX25, MX26, MX27, MX28, MX29, MX30, MX31, MX32, MX33, MX34, MX35, MX36, MX37, MX38, MX39, MX40, MX41, MX42, MX43, MX44, MX45, MX46, MX47, MX48, MX49, MX50, MX51, MX52, MX53, MX54, MX55, MX56, MX57, MX58, MX59, MX60: SW_Push; MX
MX8: SW_Push; MX_NTHSTH
R1, R7, R8: 1.5k; R_Axial_DIN0204_L3.6mm_D1.6mm_P7.62mm_Horizontal
R2, R3: 75R; R_Axial_DIN0204_L3.6mm_D1.6mm_P7.62mm_Horizontal
R4: 10k; R_Axial_DIN0204_L3.6mm_D1.6mm_P7.62mm_Horizontal
R5, R6: 5.1k; R_Axial_DIN0204_L3.6mm_D1.6mm_P7.62mm_Horizontal
SW1: RESET; SW_PUSH_6mm
SW2: BOOT; SW_PUSH_6mm
U1: ATMEGA328-PU; DIP-28_W7.62mm
Y1: 16MHz; Crystal_HC49-4H_Vertical

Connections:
+5V: C3.1, C4.1, C5.1, F1.2, J2.5, R1.2, R4.1, U1.7 (VCC), U1.20 (AVCC)
/COL0: MX1.2, MX2.2, MX3.2, MX4.2, MX5.2, MX6.2, U1.14 (PB0)
/COL1: MX7.2, MX8.2, MX9.2, MX10.2, MX11.2, MX12.2, U1.13 (PD7)
/COL2: MX13.2, MX14.2, MX15.2, MX16.2, MX17.2, MX18.2, U1.12 (PD6)
/COL3: MX19.2, MX20.2, MX21.2, MX22.2, MX23.2, MX24.2, SW2.1, U1.11 (PD5)
/COL4: 2u_MX30.2, MX25.2, MX26.2, MX27.2, MX28.2, MX29.2, MX30.2, U1.6 (PD4)
/COL5: MX31.2, MX32.2, MX33.2, MX34.2, MX35.2, MX36.2, U1.3 (PD1)
/COL6: MX37.2, MX38.2, MX39.2, MX40.2, MX41.2, MX42.2, U1.2 (PD0)
/COL7: MX43.2, MX44.2, MX45.2, MX46.2, MX47.2, MX48.2, U1.24 (PC1)
/COL8: MX49.2, MX50.2, MX51.2, MX52.2, MX53.2, MX54.2, U1.25 (PC2)
/COL9: 2u_MX60.2, MX55.2, MX56.2, MX57.2, MX58.2, MX59.2, MX60.2, U1.26 (PC3)
/LED1: R7.1, U1.28 (PC5)
/LED2: R8.1, U1.27 (PC4)
/RESET: J2.2, R4.2, SW1.1, U1.1 (~RESET/PC6)
/ROW0: D1.1 (K), D7.1 (K), D13.1 (K), D19.1 (K), D25.1 (K), D31.1 (K), D37.1 (K), D43.1 (K), D49.1 (K), D55.1 (K), U1.23 (PC0)
/ROW1: D2.1 (K), D8.1 (K), D14.1 (K), D20.1 (K), D26.1 (K), D32.1 (K), D38.1 (K), D44.1 (K), D50.1 (K), D56.1 (K), J2.4, U1.19 (PB5)
/ROW2: D3.1 (K), D9.1 (K), D15.1 (K), D21.1 (K), D27.1 (K), D33.1 (K), D39.1 (K), D45.1 (K), D51.1 (K), D57.1 (K), J2.6, U1.18 (PB4)
/ROW3: D4.1 (K), D10.1 (K), D16.1 (K), D22.1 (K), D28.1 (K), D34.1 (K), D40.1 (K), D46.1 (K), D52.1 (K), D58.1 (K), J2.3, U1.17 (PB3)
/ROW4: D5.1 (K), D11.1 (K), D17.1 (K), D23.1 (K), D29.1 (K), D35.1 (K), D41.1 (K), D47.1 (K), D53.1 (K), D59.1 (K), U1.16 (PB2)
/ROW5: D6.1 (K), D12.1 (K), D18.1 (K), D24.1 (K), D30.1 (K), D36.1 (K), D42.1 (K), D48.1 (K), D54.1 (K), D60.1 (K), U1.15 (PB1)
/USB_D+: R2.2, U1.4 (PD2)
/USB_D-: R3.2, U1.5 (PD3)
GND: C1.2, C2.2, C3.2, C4.2, C5.2, D61.2 (A), D62.2 (A), J1.A1 (GND), J1.A12 (GND), J1.B1 (GND), J1.B12 (GND), J1.S1 (SHIELD), J2.1, J3.4, J4.1, J5.4, LED1.1 (K), LED2.1 (K), R5.1, R6.1, SW1.2, SW2.2, U1.8 (GND), U1.22 (GND)
unnamed: D1.2 (A), MX1.1
unnamed: D2.2 (A), MX2.1
unnamed: D3.2 (A), MX3.1
unnamed: D4.2 (A), MX4.1
unnamed: D5.2 (A), MX5.1
unnamed: D6.2 (A), MX6.1
unnamed: D7.2 (A), MX7.1
unnamed: D8.2 (A), MX8.1
unnamed: D9.2 (A), MX9.1
unnamed: D10.2 (A), MX10.1
unnamed: D11.2 (A), MX11.1
unnamed: D12.2 (A), MX12.1
unnamed: D13.2 (A), MX13.1
unnamed: D14.2 (A), MX14.1
unnamed: D15.2 (A), MX15.1
unnamed: D16.2 (A), MX16.1
unnamed: D17.2 (A), MX17.1
unnamed: D18.2 (A), MX18.1
unnamed: D19.2 (A), MX19.1
unnamed: D20.2 (A), MX20.1
unnamed: D21.2 (A), MX21.1
unnamed: D22.2 (A), MX22.1
unnamed: D23.2 (A), MX23.1
unnamed: D24.2 (A), MX24.1
unnamed: D25.2 (A), MX25.1
unnamed: D26.2 (A), MX26.1
unnamed: D27.2 (A), MX27.1
unnamed: D28.2 (A), MX28.1
unnamed: D29.2 (A), MX29.1
unnamed: 2u_MX30.1, D30.2 (A), MX30.1
unnamed: D31.2 (A), MX31.1
unnamed: D32.2 (A), MX32.1
unnamed: D33.2 (A), MX33.1
unnamed: D34.2 (A), MX34.1
unnamed: D35.2 (A), MX35.1
unnamed: D36.2 (A), MX36.1
unnamed: D37.2 (A), MX37.1
unnamed: D38.2 (A), MX38.1
unnamed: D39.2 (A), MX39.1
unnamed: D40.2 (A), MX40.1
unnamed: D41.2 (A), MX41.1
unnamed: D42.2 (A), MX42.1
unnamed: D43.2 (A), MX43.1
unnamed: D44.2 (A), MX44.1
unnamed: D45.2 (A), MX45.1
unnamed: D46.2 (A), MX46.1
unnamed: D47.2 (A), MX47.1
unnamed: D48.2 (A), MX48.1
unnamed: D49.2 (A), MX49.1
unnamed: D50.2 (A), MX50.1
unnamed: D51.2 (A), MX51.1
unnamed: D52.2 (A), MX52.1
unnamed: D53.2 (A), MX53.1
unnamed: D54.2 (A), MX54.1
unnamed: D55.2 (A), MX55.1
unnamed: D56.2 (A), MX56.1
unnamed: D57.2 (A), MX57.1
unnamed: D58.2 (A), MX58.1
unnamed: D59.2 (A), MX59.1
unnamed: 2u_MX60.1, D60.2 (A), MX60.1
unnamed: D61.1 (K), J1.A6 (D+), J1.B6 (D+), J3.3, J4.2, J5.3, R2.1
unnamed: D62.1 (K), J1.A7 (D-), J1.B7 (D-), J3.2, J4.3, J5.2, R1.1, R3.1
unnamed: J1.A5 (CC1), R5.2
unnamed: J1.B5 (CC2), R6.2
unnamed: F1.1, J1.A4 (VBUS), J1.A9 (VBUS), J1.B4 (VBUS), J1.B9 (VBUS), J3.1, J4.4, J5.1
unnamed: LED1.2 (A), R7.2
unnamed: LED2.2 (A), R8.2
unnamed: C2.1, U1.9 (XTAL1/PB6), Y1.1
unnamed: C1.1, U1.10 (XTAL2/PB7), Y1.2

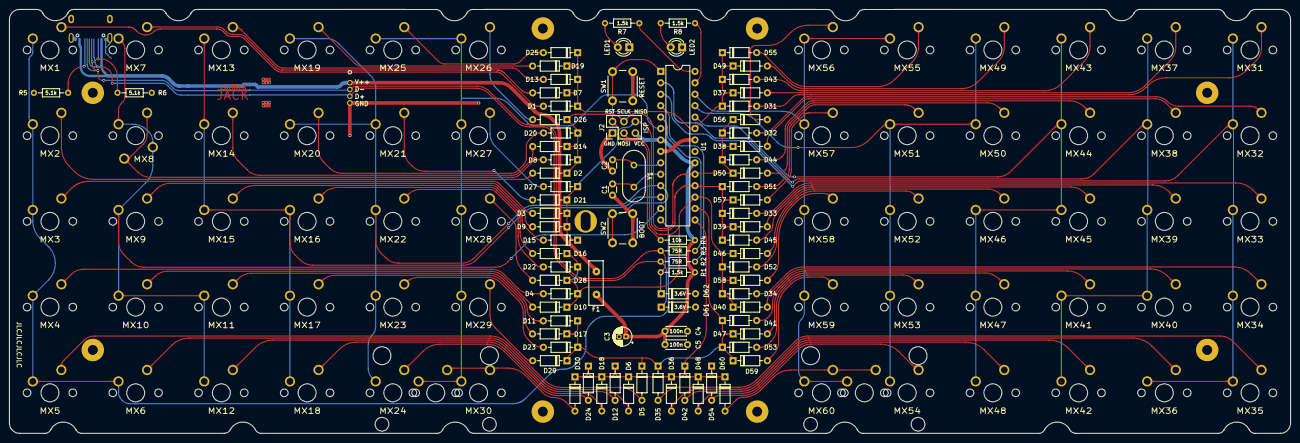
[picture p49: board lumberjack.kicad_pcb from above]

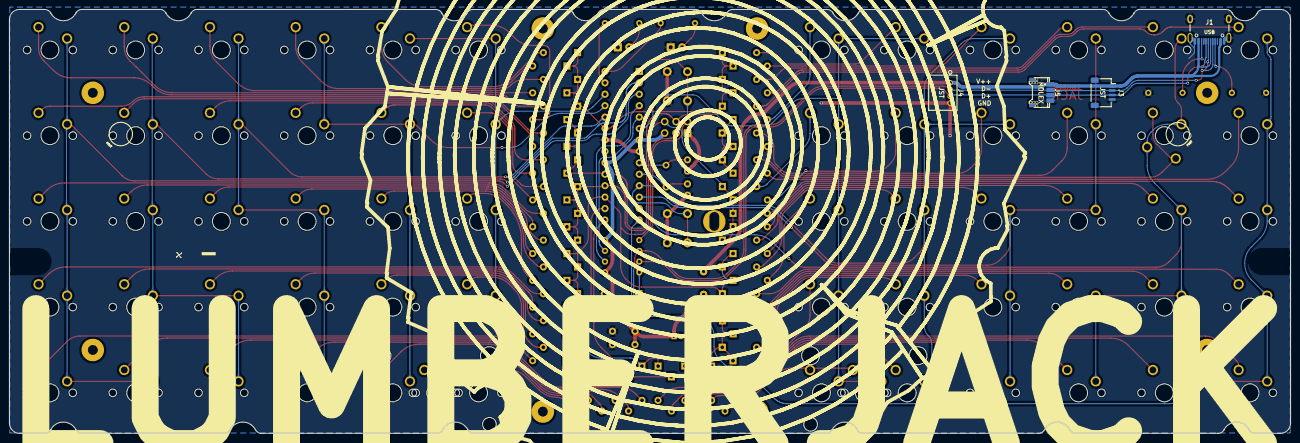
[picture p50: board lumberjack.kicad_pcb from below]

Board: 2 copper layers, 284.7 x 94.2 mm, 160 parts (4 on the bottom side), 92 nets.

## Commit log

2020-10-21 Add gerbers
    [lumberjack-B_Cu.gbr, lumberjack-B_Mask.gbr, lumberjack-B_Paste.gbr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]
2020-10-24 Add center post mounting hole
    [lumberjack-B_Cu.gbr, lumberjack-B_Mask.gbr, lumberjack-B_Paste.gbr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]
2020-11-02 Move components to allow fuse to lie flat
    [lumberjack-B_Cu.gbr, lumberjack-B_Mask.gbr, lumberjack-B_Paste.gbr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]
2020-11-03 Update gerbers
    [lumberjack-B_Cu.gbr, lumberjack-B_Mask.gbr, lumberjack-B_Paste.gbr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]
2020-11-04 Adjust fuse footprint
    [lumberjack-B_Cu.gbr, lumberjack-B_Mask.gbr, lumberjack-B_Paste.gbr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]
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2020-11-22 Fix cosmetic errors in silkscreen
    [lumberjack-B_Cu.gbr, lumberjack-B_Mask.gbr, lumberjack-B_Paste.gbr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]
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2020-12-31 Increase resistor footprint size
    [lumberjack.kicad_pcb, lumberjack.sch]
2020-12-31 Fix R1 resistor connection to D-
    [lumberjack-B_Cu.gbr, lumberjack-B_Mask.gbr, lumberjack-B_Paste.gbr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]
2021-01-07 Add SVG outline for component cover
    [cover.dxf]
2021-01-10 Rotate central mount hole 90 degrees
    [lumberjack-B_Cu.gbr, lumberjack-B_Mask.gbr, lumberjack-B_Paste.gbr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]
2021-01-23 Add JST socket footprint for USB daughterboard
    [lumberjack.kicad_pcb, lumberjack.sch]
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2021-02-05 Add optional USB-C connector and resistors
    [lumberjack-B_Cu.gbr, lumberjack-B_Mask.gbr, lumberjack-B_Paste.gbr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]
2021-02-28 Move USB-C resistors to top row
    [lumberjack-B_Cu.gbr, lumberjack-B_Mask.gbr, lumberjack-B_Paste.gbr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]
2021-03-06 Update signature silk
    [lumberjack-B_Cu.gbr, lumberjack-B_Mask.gbr, lumberjack-B_Paste.gbr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]
2021-03-06 Add FR4 plate files
    [plate-B_Cu.gbl, plate-B_Mask.gbs, plate-B_Paste.gbp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]
2021-03-06 Fix diode number in readme
2021-03-06 Add copper layer to plate PCB
    [plate-B_Cu.gbl, plate-B_Paste.gbp, plate-B_SilkS.gbo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]
2021-03-07 Fix naming of zener diode footprints
    [lumberjack-B_Cu.gbr, lumberjack-B_Mask.gbr, lumberjack-B_Paste.gbr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]
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2021-03-19 Adjust screw hole in plate file
    [plate-B_Cu.gbl, plate-B_Mask.gbs, plate-B_Paste.gbp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]
2021-03-19 Add plate DXF file
    [plate.dxf]
2021-04-14 Fix plate and cover DXF file outlines
    [cover.dxf, plate.dxf]
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2021-06-07 Update zener diode names in BOM and build guide
2021-08-10 Update BOM and guide with yellow C1 & C2 capacitor images
2021-08-21 Move plate files into own folder
    [lumberjack-full-B_Cu.gbl, lumberjack-full-B_Mask.gbs, lumberjack-full-B_Paste.gbp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]
2021-08-21 Add Brutal60 plate files
    [brutal60-full-B_Cu.gbl, brutal60-full-B_Mask.gbs, brutal60-full-B_Paste.gbp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]
2021-08-21 Fix guide for C3 capacitor
2021-09-18 Add copper outline to split plate
    [lumberjack-split-B_Cu.gbl, lumberjack-split-B_Mask.gbs, lumberjack-split-B_Paste.gbp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]
2021-09-18 Add missing copper fill to full plate
    [lumberjack-full-B_Cu.gbl, lumberjack-full-B_Mask.gbs, lumberjack-full-B_Paste.gbp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]
2021-09-18 Add missing copper fill to split Brutal60 plate
    [brutal60-split-B_Cu.gbl, brutal60-split-B_Mask.gbs, brutal60-split-B_Paste.gbp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]
2021-09-18 Add missing copper fill to full Brutal60 plate
    [brutal60-full-B_Cu.gbl, brutal60-full-B_Mask.gbs, brutal60-full-B_Paste.gbp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]
2021-10-10 Add via to split plate
    [lumberjack-split-B_Cu.gbl, lumberjack-split-B_Mask.gbs, lumberjack-split-B_Paste.gbp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]
2021-10-14 Use USB footprint with better positioning
    [lumberjack-B_Cu.gbr, lumberjack-B_Mask.gbr, lumberjack-B_Paste.gbr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]
2021-10-16 Move 5.1k resistors to better location
    [lumberjack.kicad_pcb]
2021-10-16 Change MX8 to allow both north and south facing switch
    [lumberjack.kicad_pcb]
2021-11-23 Add through-hole JST connector footprint
    [lumberjack.kicad_pcb, lumberjack.sch]
2021-11-23 Update gerber files
    [lumberjack-B_Cu.gbr, lumberjack-B_Mask.gbr, lumberjack-B_Paste.gbr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]
2021-11-23 Adjusted wording around C3 capacitor in build guide
2021-12-26 Change switch footprint to also support Alps & Choc
    [lumberjack.kicad_pcb, lumberjack.sch]
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2022-02-25 Remove extra support pin from Choc footprint
    [lumberjack-B_Cu.gbr, lumberjack-B_Mask.gbr, lumberjack-B_Paste.gbr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]
2022-02-25 Move switch silkscreen to top of PCB
    [lumberjack.kicad_pcb]
2022-02-25 Revert to more spacious hybrid USB design
    [lumberjack-B_Cu.gbr, lumberjack-B_Mask.gbr, lumberjack-B_Paste.gbr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]
2022-02-25 Add FR4 plate with Alps mount holes
    [lumberjack-alps-B_Cu.gbl, lumberjack-alps-B_Mask.gbs, lumberjack-alps-B_Paste.gbp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]
2022-02-25 Add information to guide about using tall capacitors
2022-02-25 Enlarge full plate center cutout
    [lumberjack-full-B_Cu.gbl, lumberjack-full-B_Mask.gbs, lumberjack-full-B_Paste.gbp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]
2022-02-25 Add full Alps plate
    [lumberjack-alps-full-B_Cu.gbl, lumberjack-alps-full-B_Mask.gbs, lumberjack-alps-full-B_Paste.gbp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]
2022-02-25 Add DXF plot for full plate
    [lumberjack-full.dxf]
2022-02-25 Add plate for Polaris
    [lumberjack-polaris.dxf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]
2022-02-25 Reorganise plate files
    [brutal60-full.kicad_pcb, brutal60-split.kicad_pcb, lumberjack-alps-full.kicad_pcb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]
2022-02-25 Add extra standoff mounting holes
    [lumberjack-B_Cu.gbr, lumberjack-B_Mask.gbr, lumberjack-B_Paste.gbr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]
2022-02-26 Bump rev number on silkscreen
    [lumberjack-B_Cu.gbr, lumberjack-B_Mask.gbr, lumberjack-B_Paste.gbr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]
2022-04-03 Add information about JST connector to build guide
2022-04-03 Add cutouts for CK Bakeneko
    [lumberjack-B_Cu.gbr, lumberjack-B_Mask.gbr, lumberjack-B_Paste.gbr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]
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2022-05-02 Set correct cover screw length in BOM
2022-05-19 Add 3D printable component cradles
    [BlueResistorCradles_x6.stl, CrystalCradle_x1.stl, LEDcradle_x2.stl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]
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2022-06-06 Add copper outline to MX plates
    [lumberjack-full-B_Cu.gbl, lumberjack-full-B_Mask.gbs, lumberjack-full-B_Paste.gbp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]
2022-11-27 Add Frog Mini plate
    [frog-mini-B_Cu.gbl, frog-mini-B_Fab.gbr, frog-mini-B_Mask.gbs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]
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2022-12-27 Update to KiCad 6 file format
    [lumberjack.kicad_pcb, lumberjack.kicad_sch, lumberjack.sch]
2023-02-02 Revert to the correct version of the schematic, synchronize PCB with schematic (#11)
    [lumberjack.kicad_pcb, lumberjack.kicad_sch]
2023-02-23 Fix copper outline missing on the back side of MX split plates
    [lumberjack-full-B_Cu.gbl, lumberjack-full-B_Mask.gbs, lumberjack-full-B_Paste.gbp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]
2023-04-10 Replace hybrid USB footprint with plain USB-C
    [lumberjack.kicad_sch]
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2023-04-27 Switch to SMD USB-C connector
    [lumberjack-B_Cu.gbr, lumberjack-B_Mask.gbr, lumberjack-B_Paste.gbr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]
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2024-03-20 Add Molex connector footprint
    [lumberjack.kicad_pcb, lumberjack.kicad_sch]
2026-10-06 Add vendor store links for sourcing parts in Japan to BOM

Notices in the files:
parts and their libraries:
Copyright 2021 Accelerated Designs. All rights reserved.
